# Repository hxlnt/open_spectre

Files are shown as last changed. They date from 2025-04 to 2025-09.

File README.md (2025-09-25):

# OPEN_SPECTRE
## An open-source FPGA-based EMS SPECTRE video synth.
*A project aimed at recreating the EMS SPECTRE VIDEO SYNTHESIZER in HDL*

###  ✨The EMS SPECTRE Colour Video ✨
>Synthesizer is a unique and revolutionary new product: an instrument capable of producing exciting graphic images on an ordinary television screen. The complete SPECTRE package consists of the synthesizer itself, plus a Sony Trinitron colour monitor, and a Sony black-and-white TV camera. The synthesizer is compact (38"x23.5"x7"), portable (about 35 pounds/15.9KG), and unequalled in its simplicity and versatility.

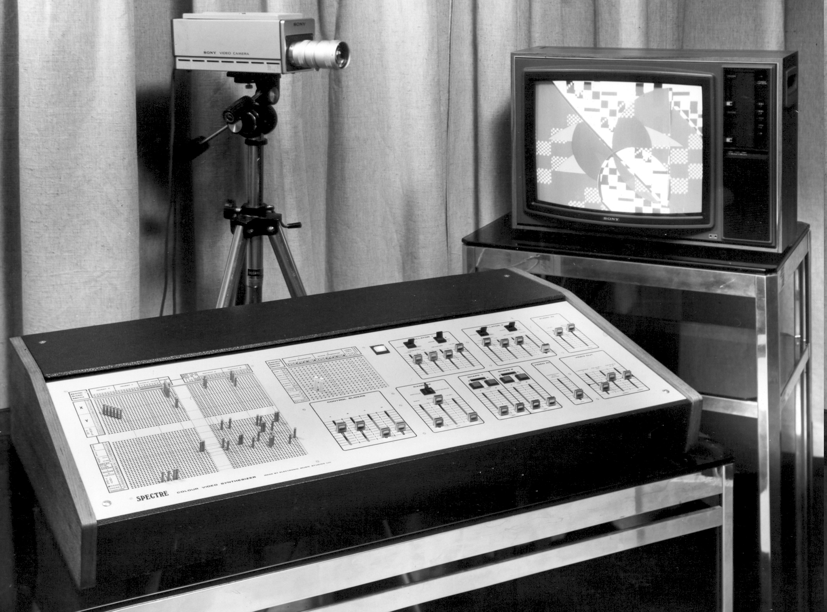
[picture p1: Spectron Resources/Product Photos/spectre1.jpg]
EMS SPECTRE


### Design Info
#### 🎉Aim 🎉
The aim of this project is to preserve this rare and unique video synth by recreating it in an FPGA, but also to use it as a building block to make a Spectre that is both true to the original and also a modern tool for creativity.
For more info in this process take a look at: 
[Cloning Hardware Ethos](documentation/Cloning%20a%20process%20not%20a%20device.md)

### 🍣Want to Contribute?🍣
Amazing! If you have FPGA and or Verilog/VHDL skills we would love to have you involved. But, first, there are a few things you should know. 
#### What to do first
- Look through the resources folder to get an idea of what the EMS SPECTRE is and how it works
- Look at the top-level diagram and the list of modules
#### Project Details For Contributors
- RTL in VHDL or Verilog (VHDL preferred, no system Verilog 😎 sorry) 
- One module per file with a separate testbench (Verilog or VHDL test benches only, *not everything has one yet, but it should)
- Test benches should print out a message at the end confirming if they are successful or not
- No HSL or auto-generated code, no busses or interfaces for now (will be busses later)
- Use any software you like, but a Vivado project will be supplied
- Follow the template for file headers and comments 📑
- Follow the folder structure for the project 📂
- All code must be open source or MIT license 👍

#### If after all that you still want to be involved you can do one of three things:
- Email us at *OPEN.SPECTRE.PROJECT@gmail.com* and see what modules we need to make at the moment
- Branch the repo, make a module, and submit a pull request 
- If you are not any good at git/GitHub, if you write any modules you can email them to us and we will integrate them into the project

### 🐙License🐙
Creative Commons CC BY-NC

### Contributors
-Remi Freer
-Jacob Stoker
-Robert D Jordan

### Donations
We are very thankful to have received donations from the following people:
Chris Korvin,
Jay Hotchin,
Milton Grimshaw, and more amazing anonymous people.

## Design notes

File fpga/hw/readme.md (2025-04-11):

using this dev board:
https://www.aliexpress.com/item/1005005961199362.html?spm=a2g0o.order_list.order_list_main.76.1cc71802oC4QSS
https://github.com/ChinaQMTECH/QMTECH_XC7A15T_35T_CSG325_CORE_BOARD

use these libs
https://github.com/jmwilson/Adafruit-GFX-Library_MicroBlaze
https://github.com/jmwilson/Adafruit_SSD1306_MicroBlaze

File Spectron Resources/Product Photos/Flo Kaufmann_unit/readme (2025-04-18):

Photos of Flo Kaufmann's, generously sent.
Lots of good images of the PCBs

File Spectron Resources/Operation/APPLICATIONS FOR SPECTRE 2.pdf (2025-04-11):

### APPLICATIONS FOR SPECTRE

Spectre is versatile enough to have applications in many diverse fields. Video has already become an aid to education and industry in many ways; Spectre, as a low cost, self-contained video studio is ideal for the school or business wishing to take advantage of video technology. For any educational institution, Spectre will be invaluable as a tool for teaching principles of design, colour, and concepts of digital logic. Students can create works which are easily stored, permanently or temporarily, on videotape, and can be duplicated as easily as with audio recordings. For artists and video production studios, the applications are obvious. As well as being able to perform special effects with less hardware than is usual, Spectre can be used as a live performance instrument, for which there is no comparable system presently available In industry, Spectre will be extremely useful in fields such as fabric and wallpaper design, where a simple photograph of the monitor screen would substitute for painstaking artist's renditions. Black and white images of products or advertisements can be colourised and particular colours or combinations thereof substituted or recalled in an instant. To add to its commercial applications, Spectre is entertaining as well as useful. Its accessibility to even the most inexperienced of users will make it a unique attraction in any situation where entertainment is sought.

OPERATION OF SPECTRE
All patching of functions in Spectre is done by means of pin board matrix connections. Signals coming out of functions appear at horizontal positions (rows) and inputs to functions as well as to the final output, are at vertical positions (columns). Outputs are labelled at the left side of the pin matrix, inputs at the top. In order to produce an image on the monitor screen, signals must eventually reach the input columns of either Output A or Output B, on the Digital Signal Matrix.
Spectre has three types of digital output - luminance, colour 1 and colour 2 - which combine to send particular signal levels to the video output. There are 16 levels of luminance eight levels of each colour, making a total of 64 colour possibilities at any of 16 luminance levels. It is by manipulating the digital signals that produce these levels that we form images on the monitor screen.
In order to operate Spectre effectively, it is helpful to have a basic understanding of digital logic:- Digital signals have only two states: they are either high or low. There are three kinds of operations used to combine digital signals and produce a particular output. These are:
The AND Operation: The output is high only where all inputs are high; where any input is low, the output is low. The OR Operation: The output is high where any input is high; output is low only where all inputs are low. The Exclusive OR Operation: The output is high where only one of two inputs is high; where the two in puts are in the same state the output is low.
With nothing patched on the Digital Signal Matrix, all the digital outputs 'float' high. Signals patched to an output column are combined by the AND operation so that the output will go low wherever the input signal is low. We are, in effect, 'carving' images out of a back screen. With no patching the screen will appear dark. Patching X position 2 (a signal which goes low, high, low, high, low across the screen) to luminance 0 will produce light vertical bands:
The light bands indicate where the luminance signal has been pulled low. Patching X2 also to one of the colour outputs will pull that colour signal low, so that the light bands now have a hue that is the combination of Luminance 0 and one Colour input in the low state, all others in the high state. Input signals patched to the same column also combine by the AND operation.

Beginning as before, with X2 patched to Luminance 0, now patch X4 also to Luminance 0. X4 goes low, high, faster than X2, so producing narrower bands. The bands of X4 will appear only in the positive (high) areas of X2. The dark area on the screen now represents the combined high output of X2 and X4. Output A and Output B are identical, and are combined by the Exclusive OR operation to produce the final digital output of the synthesizer.
To produce a simple checkerboard effect then, we would patch X2 to Luminance 0 at Output A. Now, by patching Y2 to Luminance 0 at Output B, the high level will appear wherever X and Y are in opposite states, the low level wherever they are in the same state. Referring to the graphs at the bottom of page 2, the screen appears like the Exclusive OR graph, repeated several times, dark at the high level, and light at the low level: The effect of any signal may be inverted by grounding the respective input column of the opposite Output That is, if X2 is patched to Luminance 0 at Output A, patching Luminance 0 at Output B to ground will produce this:

SPECTRE FUNCTIONS
Digital Signal Matrix
X and Y positions
Produce horizontal and vertical bands. Each level (0-8) is twice the frequency of the level above it, thus producing bands half the width of the one before.
Overlay Gates (1-4)
Allows superimposition of images. Inputs to SIG appear only where the input to DIS is low.
Inverts (1-4)
Signals sent to Invert inputs appear inverted (high goes low, low goes high) at the Invert out row.
Edge
Creates an image of the border of the signal at the Edge input. If we scan the screen from left to right, we can speak of signals as "rising" where they change from low to high, "falling" where changing from high to low. The + output of the Edge is the border of the rising side of the input signal, - is the border of the falling side.
Delay
Creates "echoes" of signals by reproducing the input signal in the state it was in a microsecond before.
Flip-Flop
Similar to Edge, creating a low signal where the input signal changes state, but extending the edge of the screen. If we send a circle as signal input:
The Flip Flop + output appears:
The Flip-Flop - output appears:
Slow Counter
A signal going high and low at six different frequencies. Can be combined with other functions to produce various timed effects, such as to disenable a signal at an overlay gate
Shape Outputs
There are four separate shape outputs, each of which can produce any of sixteen different signals, as determined by the Shape Select on the right side of the face panel.
Each of these sixteen signals is a basic form which can be modified by a control voltage (such as an Oscillator or Audio signal). Control signal inputs are available on the Analogue Control Matrix (see Shape Select and Shape Generator Control).

Video Input
An input from an external black and white video source (connected via the back panel socket) passes through a comparator in the synthesizer. The comparator divides the grey scale of the video image into seven different levels. These levels appear as digital signal outputs on the Digital Signal Matrix, so that, each of the levels can be individually coloured or patternised. The video output may also be processed through any of the SPECTRE functions, such as Edge or Flip-Flop, for other special effects.
Invert X and Y
Signals at these inputs will cause the corresponding X or Y output to change state wherever the input signal is low. Another way of producing the checkerboard pattern used as an example on page three, is to patch X2 to any level, then patch Y2 to Invert X2.
Colour Swap
Signals patched to any colour are switched to the same level of the opposite colour whenever the input at Colour Swap is low.

Analogue Control Matrix and Sliders
Oscillators 1 and 2
Produce sine and square waves, with slider controls for coarse and fine frequency and amplitude level. Frequency can be switched to one of three ranges. Sync control allows the oscillator to be synched to integer multiples of either the line or frame frequency of the monitor. This allows the effect of the oscillator on an image to remain stable.
Audio Input
Produces an amplitude contour of the treble and bass ranges, or their composite, of any external audio signal. This signal may then be used to alter any voltage controllable parameter of an image.
Control Sliders
Produce voltages which remain constant at the level set on the slider.

From Signal Matrix
Signals directed to the input labelled To Control Matrix (on the Digital Signal Matrix) will appear at this output, with the choice of either the high or low state of the digital signal. Thus, for one instance, the outputs of the Slow counter may be routed to the control matrix to control an analogue function.
Video Out
Signals at these inputs control the level of the final output's luminance, colour 1 and colour 2, as they affect the monitor. Levels for these signals may also be set by face panel sliders. Comparator Level Spacing (Video Input)
This affects the level of the external video input that is directed to the comparator (described on page 5 under Video Input). At maximum, the entire video signal will pass through and be divided into seven levels. At minimum only the darkest areas of the image will pass through and be divided. As the Comparator Level slider or control voltage is changed the colours selected on the Digital Signal Matrix for any level will move from one area of the video image to the next.
Shape Select and Shape Generator Control
The Shape Selects allow the user to choose one of sixteen different signals to appear at one of the four shape outputs on the Digital Signal Matrix. The output chosen is indicated by a combination of four LED's on the Shape Select panel. The Shape Selects and Shape outputs are in pairs: outputs 1a and 1b are controlled by Shape Generator 1, likewise for outputs 2a and 2b controlled by Shape Generator 2.
The sixteen outputs are in turn derived from six basic signals (or forms) produced by the Shape Generators. There are control inputs to each of these six forms, which allow a wide range of modification to any basic form. There are also inputs to control the horizontal and vertical orientation of the forms, making a total of eight control inputs to each Shape Generator. Note that a control signal input to Shape Generator 1 will affect both Shape outputs 1a and 1b, but not 2a or 2b.

SPECTRE SYSTEMS AND ACCESSORIES
SPECTRE may be used with any ordinary television or TV monitor or adapted to the equipment of an existing video set-up. It includes both an encoded video output (either PAL or NTSC format) and a modulated (UHF) output, as well as an un-encoded output for monitors modified to accept its signals directly.
For those who do not already own video equipment, EMS recommends that SPECTRE be purchased as a package with a modified Sony Trinitron colour monitor and Sony black and white TV camera.
The Synthi AKS music synthesizer is recommended as a companion to SPECTRE, allowing a greater range of control signal possibilities, as well as audio-visual interaction.

DESCRIPTION OF COLOUR PLATES
All of the COLOUR plates were taken of images produced by the first prototype of SPECTRE, which is now in operation at the EMS studios in Putney.
Plate 1a: Geometric pattern produced with X-Y generators, with circle overlay. Video feedback is combined to produce colour shifts.
Plate 1b: Simple geometric pattern and 'zoom' shape, with feedback superimposed.
Plate 2a: Electronically-generated image using circle, gear and lantern shapes.
Plate 2b: Also purely electronic - using lantern and 'zoom' shapes, stripes produced by X generators.
Plate 3a: Complex electronically generated pattern, making extensive use of signal inverters.
Plate 3b: Black-and-white camera signal colourized and superimposed over an electronically generated background pattern.
Plate 4a: Geometric pattern with circle and feedback used to invert colours.
Plate 4b: Horizontal 'zoom' shape being modulated by the sine wave output of an oscillator, feedback superimposed.

SPECIFICATIONS
I. CONTROL SYSTEM
A. Digital Signal Matrix (allows combination, structuring and modification of basic signals)
1. Digital Signals:
9 X (Horizontal) Counter Outputs.
strip width: .12us - 30us in binary steps.
9 Y (Vertical) Counter Outputs
Strip Width: 2 lines - 512 lines in binary steps
6 Slow Counter Outputs: 2Hz - 6Hz in binary steps.
4 Shape Outputs (from two independent Shape Generators) each output is panel selectable from 16 possible basic shapes, circle, gear, lantern and triangles being just a few of these. These shapes may be modified by using the Analogue control Matrix.
7 Video Comparator Outputs - each active for a particular grey scale band of the video input. This will perform all the functions of a normal colourizer, and many more as its outputs may be combined and modified with all other matrix functions.
2 External inputs.
2. Digital Signal Modifiers:
9 X Counter Invert inputs
9 Y Counter Invert inputs
2 Flip-Flops (reset with line sync)
4 Overlay Gates (allow build-up of pattern layers) 4 Inverters
1 Edge Generator (with four outputs)
1 Delay (800us, reset with line sync)
3. Digital Matrix Outputs:
The combinations in which a signal is patched to the output columns determines its colour and brightness. There are:
4 bits for brilliance
6 bits for colour
Each bit comes from an "Exclusive OR" gate with both inputs available on the patchboard (named Output A and Output B) This allows the output of each bit to be inverted as required by the user.

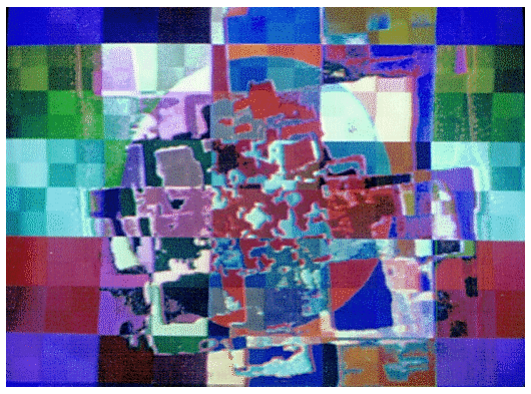
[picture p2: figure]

1 Colour Swap Output (swaps round the two colour parameters)
B. Analogue Control Matrix
(allows voltage control of the two Shape Generators, of the hue and brilliance of the final picture, and of the grey scale spacing of the video comparator.)
Control Sources:
4 Panel Sliders
2 Wide range, High Stability Oscillators 0.1Hz to 50KHz with sine or square outputs, syncable to line or frame sync.
2 Random Voltage outputs, with 'recycle' facility.
2 Envelope Follower outputs - one for bass and one for treble range of any audio input.
1 Buffered audio signal
1 External Input
2 Filtered signals from the Digital Signal Matrix
II. INPUTS
Video Input - 1v p.p. with sync. Other levels may be used if internal presets are altered.
Audio Input - 1v p.p. nominal
External Digital Inputs - normal TTL levels
External Control Inputs +/- 3v maximum
III. SYNC
Internal Sync generator allows full operation without external sync. If external sync is required, all sync inputs are on one

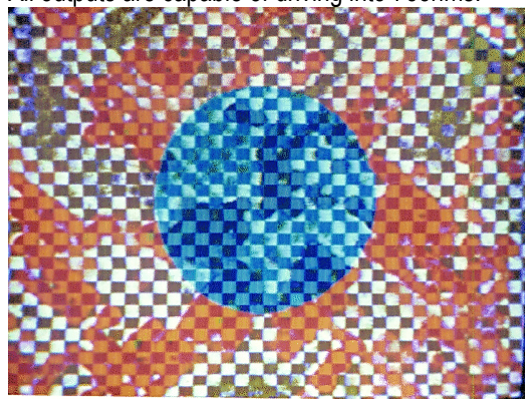
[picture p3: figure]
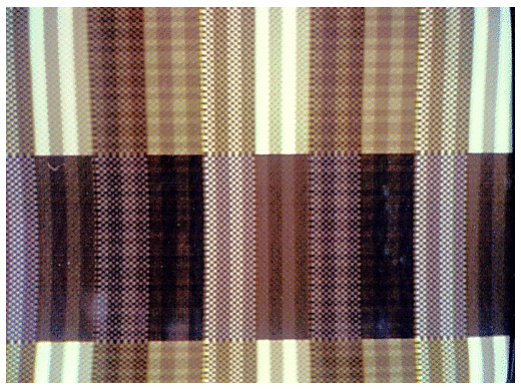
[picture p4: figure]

socket and are 2 - 5 volt -ve going pulses.
Nominal subcarrier input is 2v.
IV. OUTPUTS
Red, Green and Blue Outputs 0.7v with blanking High Resolution output (to modified Sony monitor) Composite PAL (or NTSC by request) output 1v p.p. U.H.F. Output (for direct connection to any colour TV) All outputs are capable of driving into 75ohms.

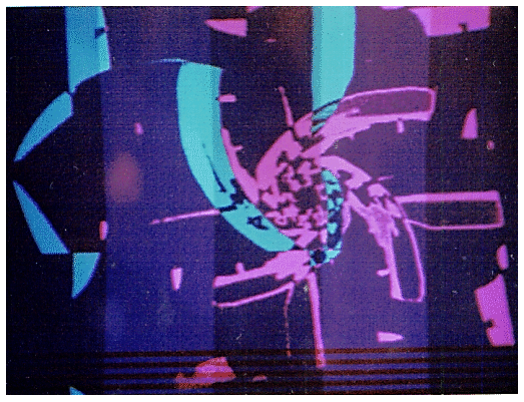
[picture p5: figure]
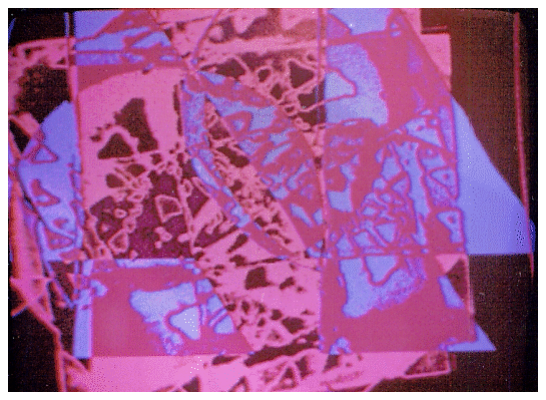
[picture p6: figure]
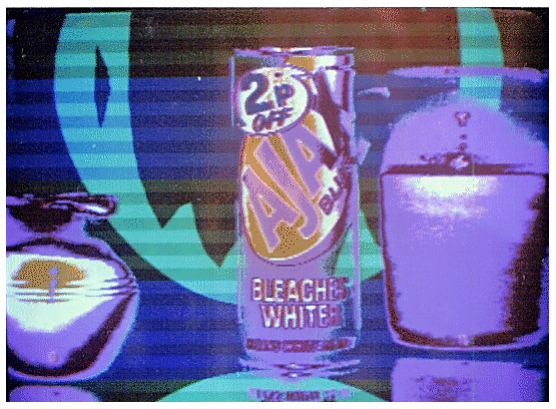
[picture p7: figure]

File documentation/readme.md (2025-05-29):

Design Hierarchy
* = tested and passed
<pre>
-------------------------------------------------------------
Hierarchy of tb_test_digital_side is:
    
**** INDIVIDUAL MODULES PASSED 100% ****
tb_test_digital_side (tested and appears fully working)
    ├─ test_digital_side : test_digital_side (*)
        │   ├─ counter : counter_re (*)
        │   ├─ counter : counter_re (*)
        │   ├─ xor18 : xy_invert_logic (*)
        │   ├─ slow_counter : slow_counter (*)
                │   ├─ pulse_generator : hz6_counter 
                │   ├─ pulse_generator : hz3_counter
                │   ├─ pulse_generator : hz1_5_counter
                │   ├─ pulse_generator : hz_6_counter
                │   ├─ pulse_generator : hz_4_counter
                │   ├─ pulse_generator : hz_2_counter
        │   ├─ nand4 : overlay_gates (*)
        │   ├─ invert_4 : inverters (*)
        │   ├─ monstable_4 : edge (*)
                │   ├─ edge_detector : ed_1 
                │   ├─ edge_detector : ed_2
                │   ├─ edge_detector : ed_3
                │   ├─ edge_detector : ed_4
        │   ├─ delay_800us : delay_800 (*)
        │   ├─ d_flipflop_ext : flip_flop1 (*)
        │   ├─ d_flipflop_ext : flip_flop2 (*)
        │   ├─ compare_7 : comparator (*)
                │   ├─ window_comparator : wc_5 (*)
                │   ├─ window_comparator : wc_4 (*)
                │   ├─ window_comparator : wc_3 (*)
                │   ├─ window_comparator : wc_2 (*)
                │   ├─ window_comparator : wc_1 (*)
                │   ├─ window_comparator : wc_0 (*)
                │   ├─ xor_n : xor_n (*)
        │   ├─ xor_n : matrix_input_inverters (*)
        │   ├─ or_matrix_full : pin_matrix (*)
                │   ├─ xpoint_or : or_mattrix 
        │   ├─ xor_n : luma_output (*)
        │   ├─ mux_5 : chroma_output (*)
                │   ├─ mux2_1 : mux1 
                │   ├─ mux2_1 : mux2
                │   ├─ mux2_1 : mux3
                │   ├─ mux2_1 : mux4
                │   ├─ mux2_1 : mux5
                │   ├─ mux2_1 : mux6
    ├─ write_file_ex : write_file_ex (* simulation only)
-------------------------------------------------------------    
</pre>
<pre>
-------------------------------------------------------------
Hierarchy of tb_analog_side is: !!NEED TO REGENERATE IS MISSING ATTENUATORS AND SLEW MODULES!!

tb_analog_side
    ├─ analog_side : analog_side 
        │   ├─ adder_12bit_nooverflow : pos_h_1_mix (*) -- these should be adder subtractors, acting more like an offset to the values from the analog matrix 
        │   ├─ adder_12bit_nooverflow : pos_v_1_mix (*)
        │   ├─ adder_12bit_nooverflow : zoom_h_1_mix (*)
        │   ├─ adder_12bit_nooverflow : zoom_v_1_mix (*)
        │   ├─ adder_12bit_nooverflow : circle_1_mix (*)
        │   ├─ adder_12bit_nooverflow : gear_1_mix (*)
        │   ├─ adder_12bit_nooverflow : lantern_1_mix (*)
        │   ├─ adder_12bit_nooverflow : fizz_1_mix (*)
        │   ├─ mixer_interface : analox_matrix (*)
                │   ├─ analog_matrix : analog_matrix (*)
                        │   ├─ audiomixer : audiomixer (*)
                        │   ├─ audiomixer : audiomixer
                        │   ├─ audiomixer : audiomixer
                        │   ├─ audiomixer : audiomixer
                        │   ├─ audiomixer : audiomixer
                        │   ├─ audiomixer : audiomixer
                        │   ├─ audiomixer : audiomixer
                        │   ├─ audiomixer : audiomixer
                        │   ├─ audiomixer : audiomixer
                        │   ├─ audiomixer : audiomixer
                        │   ├─ audiomixer : audiomixer
                        │   ├─ audiomixer : audiomixer
                        │   ├─ audiomixer : audiomixer
                        │   ├─ audiomixer : audiomixer
                        │   ├─ audiomixer : audiomixer
                        │   ├─ audiomixer : audiomixer
                        │   ├─ audiomixer : audiomixer
                        │   ├─ audiomixer : audiomixer
                        │   ├─ audiomixer : audiomixer
                        │   ├─ audiomixer : audiomixer
        │   ├─ sinwavegenerator : osc1 (*)
        │   ├─ sinwavegenerator : osc2 (*)
        │   ├─ random_voltage: random_1 (*)
                │   ├─ shift_sipo : sipo_1 (*)
                │   ├─ shift_sipo : sipo_2 (*)
                │   ├─ mux_8_to_1 : mux_random (*)
                │   ├─ counter : random_freq (*)
                │   ├─ slew_wraper : slew_output_1 (*)
                        │   ├─ moving_average : slew_fast  (*)
                        │   ├─ moving_average : slew_med (*)
                        │   ├─ moving_average : slew_slow (*)
                        │   ├─ moving_average : slew_snail (*)
                │   ├─ slew_wraper : slew_output_2 (*)
                        │   ├─ moving_average : slew_fast (*)
                        │   ├─ moving_average : slew_med (*)
                        │   ├─ moving_average : slew_slow (*)
                        │   ├─ moving_average : slew_snail (*)
        │   ├─ adder_12bit_nooverflow : y_dig_ann_mix (*)
        │   ├─ adder_12bit_nooverflow : u_dig_ann_mix (*)
        │   ├─ adder_12bit_nooverflow : v_dig_ann_mix (*)
        │   ├─ yuv_levels : yuv_out_levels (*)
                │   ├─ alphablend : alphablend (*)
                │   ├─ alphablend : alphablend (*)
                │   ├─ alphablend : alphablend (*)
-------------------------------------------------------------
</pre>

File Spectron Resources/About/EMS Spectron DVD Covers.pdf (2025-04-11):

# EMS Spectron Video Synthesizer

The EMS Colour Video Synthesizer is a completely unique and revolutionary development in video hardware. The Spectron is an instrument capable of creating exciting graphic image on an ordinary television screen. It can be used to process and manipulate images fed to it from a TV camera or VTR, or to create dramatic and evocative abstract images without the need for an external signal source.

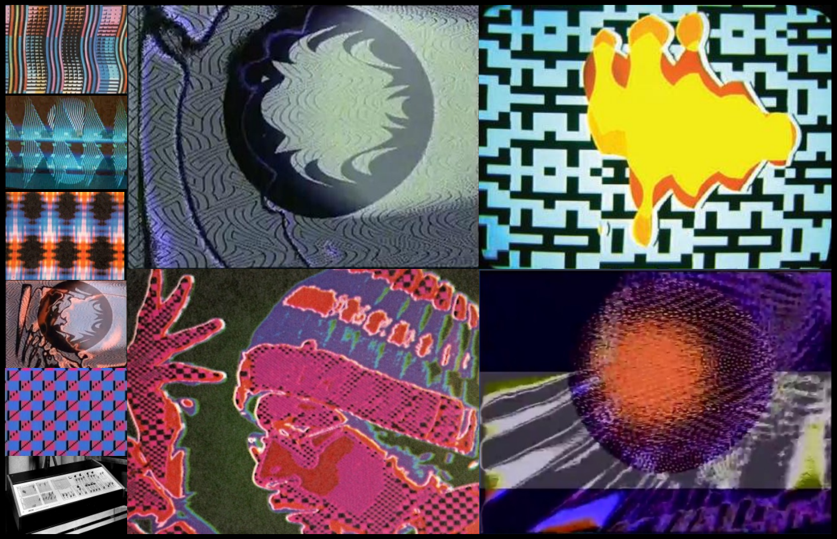
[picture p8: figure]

The Spectron Video Synthesizer is similar to the now familiar audio synthesizer. It incorporates a number of separate functions which can be selected and combined by the user by means of patch boards on the front face panel. The number of possible combinations is virtually infinite, allowing an unlimited variety of images, colours and patterns to be produced. Two specially-prepared DVDs are presented showcasing the capabilities and functions of the Spectron along with technical information and a rich source of visual references. Along with the many examples of Spectron-generated video graphics are picture galleries, information on Richard Monkhouse (the Spectron’s electronics designer and engineer), the article the Moving Art of Video Graphics, and information on video synthesis as an evolutionary phenomenon.

# EMS Spectron Video Synthesizer

A selected variety of examples has been chosen to portray the unique capabilities of the Spectron video synthesizer. All examples have been re-mastered and prepared in wide-screen format with additional sound as required.

DISC 1 | RM Spectron Demonstrations Mother Earth by Zorch Le Entrapercu by Robert Cahen Lucifer Photophore Quad Display Labyrinthe Fluides with Information Text Variations Video I – Jacques Guyonnet Horizontales Couleurs – Robert Cahen Artmatique – Robert Cahen Art Electronique
DISC 2 | Telex – Twist a St. Tropez Tangerine Dream Richocet Excerpt Todd Rundgren – All The Children Sing Plastic Bertrand – Ca Plane Pour Moi Indefinite Objects Quad Display Sans Soleil Film Spectron Excerpts EMS Spectron Logic Demonstrations Indefinite Objects NVC

SPECIAL FEATURES
| Technical Information Picture Gallery Richard Monkhouse & the EMS Spectron The Moving Art of Video Graphics Spectron Grammar Video Synthesis Directions

DVD videos for personal reference material only.

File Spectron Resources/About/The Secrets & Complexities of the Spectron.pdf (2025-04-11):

# THE SECRETS & COMPLEXITIES OF THE SPECTRON

FEEDBACK EFFECTS
Surreal effects can be produced by incorporating optical video feedback into the signal chain, and using the extensive image processing capability of the Spectron to produce all kinds of inverted colourisation effects, negative imagery, and effects that can “shimmer” or “vibrate” on the screen. Here, the Spectron is used as a kind of colourisation vision mixer.

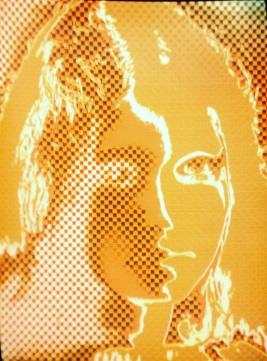
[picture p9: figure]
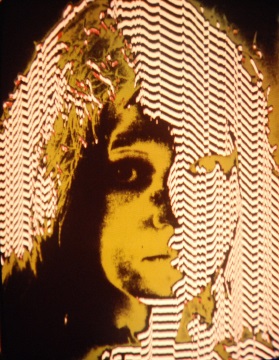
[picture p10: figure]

COUNTER ADDITION EFFECTS

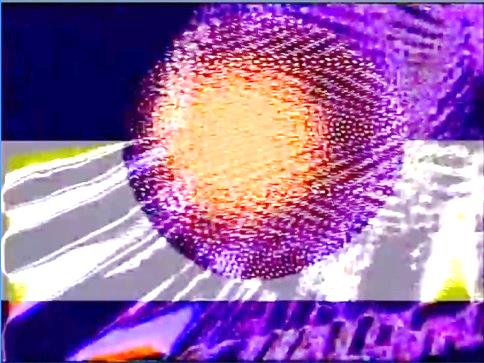
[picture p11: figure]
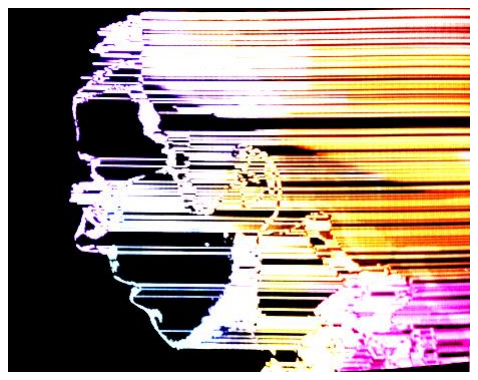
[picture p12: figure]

Sets of pins in the same “column” on the patch board do a wired OR function. If you OR a series of X counter outputs one obtains thin vertical lines. If one then performs an XOR to the INVERT input of each X counter bit with the appropriate Y counter, one effectively makes a kind of digital adder, and the vertical lines can be turned into diagonal lines. Experimentation can yield diamond patterns and other variations of diagonally-formed combinations.

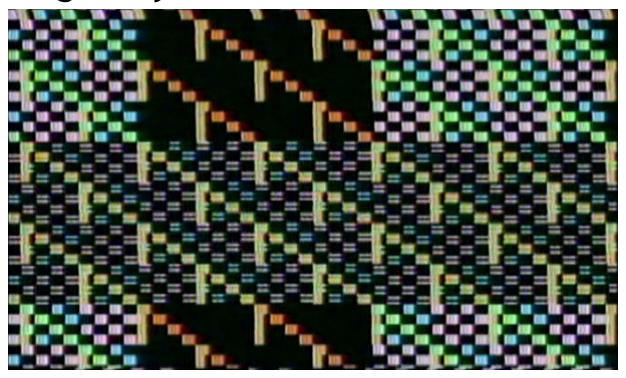
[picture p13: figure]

FRACTALS

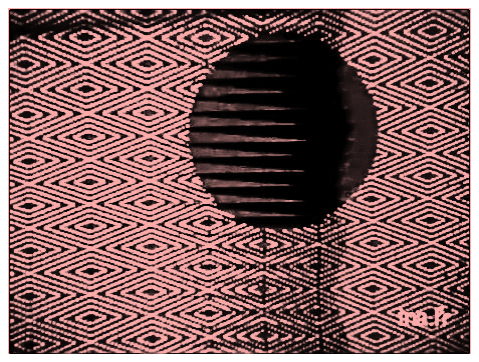
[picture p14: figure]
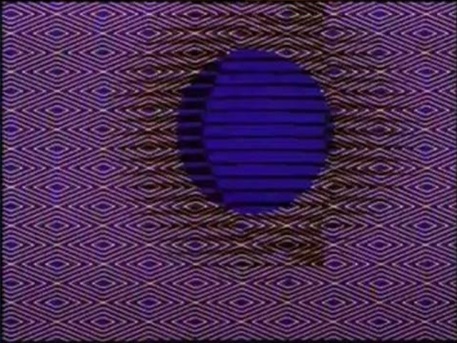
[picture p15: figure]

Quite complex “fractal-like” patterns can be produced by integrating generators and processors with an internal feedback loop. Feedback can be created by the ACM controlling a shape generated and fed into the DSM, which in turn cycles back to the analogue domain.

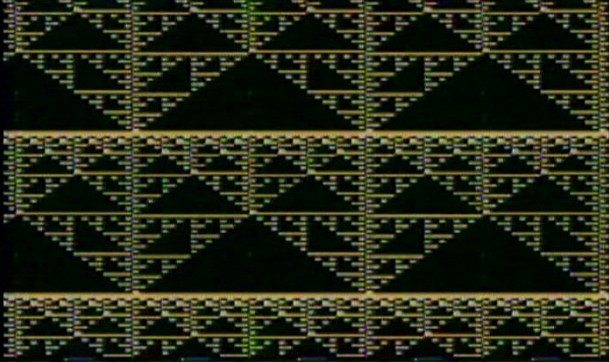
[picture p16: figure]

THE UNEXPLAINED

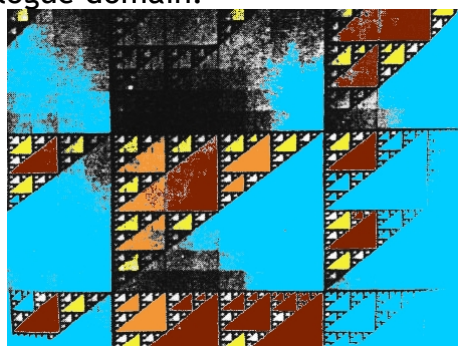
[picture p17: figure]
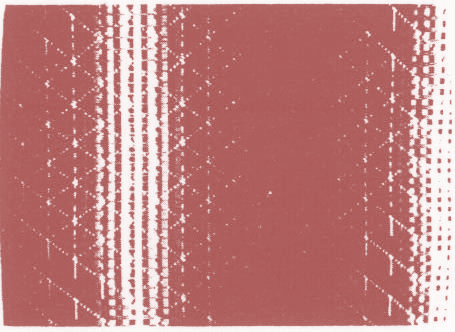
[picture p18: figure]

One of the mysteries of the counter logic combinations is the “maze patch” from the Labyrinthe Fluides video by Genevieve Calame & Jacques Guyonnet. The “digital adder” technique is used here with the X and Y counters in a particular combination that has not been explained. All that is known is that many, if not all, logic combinations of a set of binary bits can be made by asymmetric functions such as AND and OR, and inversion symmetrical controlled inversion , ie. XOR.

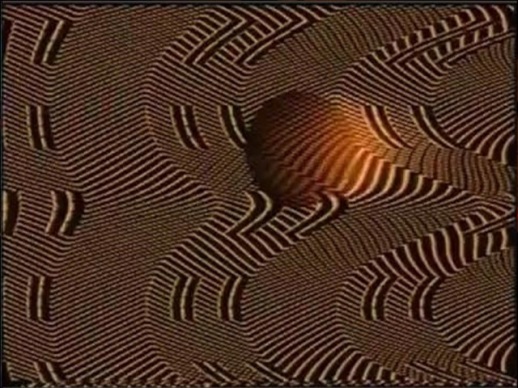
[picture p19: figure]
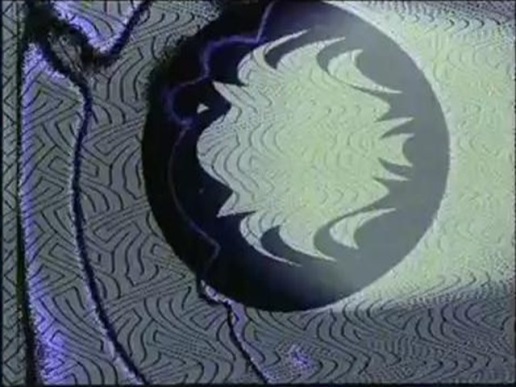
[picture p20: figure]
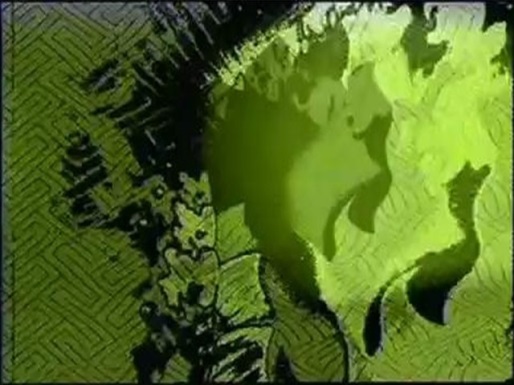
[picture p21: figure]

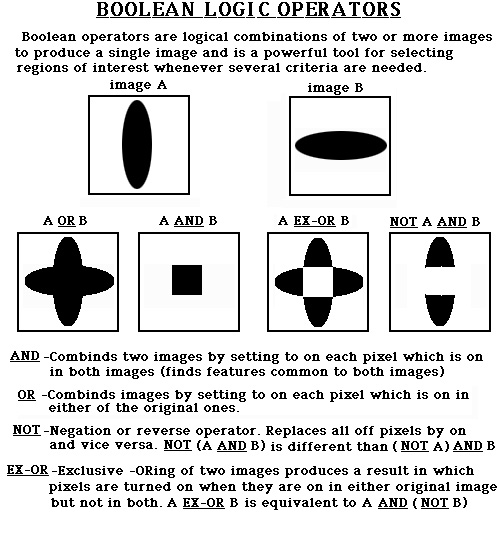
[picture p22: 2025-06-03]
Spectron Resources/Product Photos/Boolean Logic.jpg

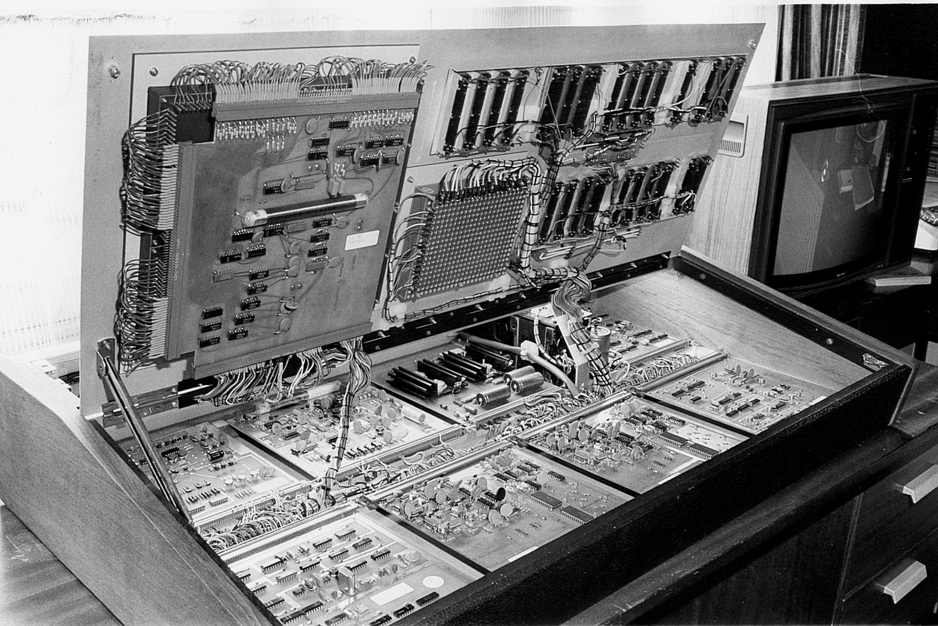
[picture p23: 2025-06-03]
Spectron Resources/Product Photos/spectre2x.jpg

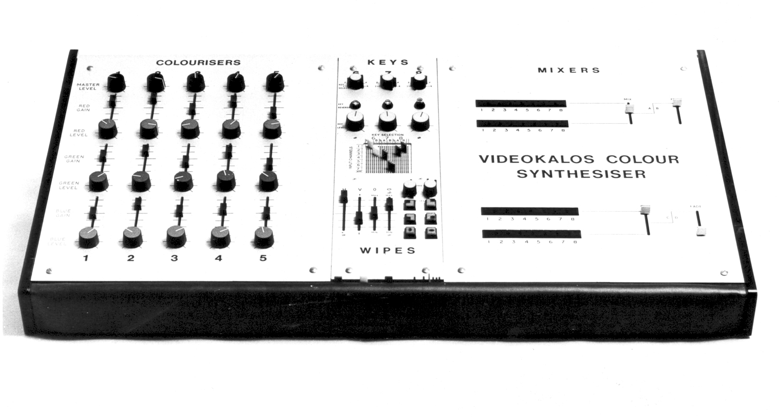
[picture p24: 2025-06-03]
Spectron Resources/Product Photos/Other machines/videok.jpg

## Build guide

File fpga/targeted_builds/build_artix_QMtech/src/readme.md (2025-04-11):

Files used in the hardware proto build On QMtech artix dev board

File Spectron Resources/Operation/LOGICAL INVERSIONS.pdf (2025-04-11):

## LOGICAL INVERSIONS & EXCLUSIVE OR (XOR) TRANSFORMATIONS

Linear counters (horizontal & vertical) and checkerboard patterns are transformed by the XOR logical transformation and linear movements that are imparted. Several orders of XOR logic and track-matte functions create complex combinations from simple patterned effects.

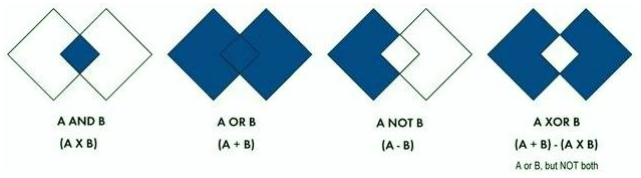
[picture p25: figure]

Logical AND, OR and XOR combinations produce many complex visualisations that can create startling optical animations. The full visual potential of the exclusive OR (XOR) function on linear and checkerboard patterns has yet to be realised. Because of the availability of the XOR effect on any image within the video layers, the power of XOR goes well beyond simple inversion. This is the appeal of the XOR - pure logic functioning that transcends the concept of the image.

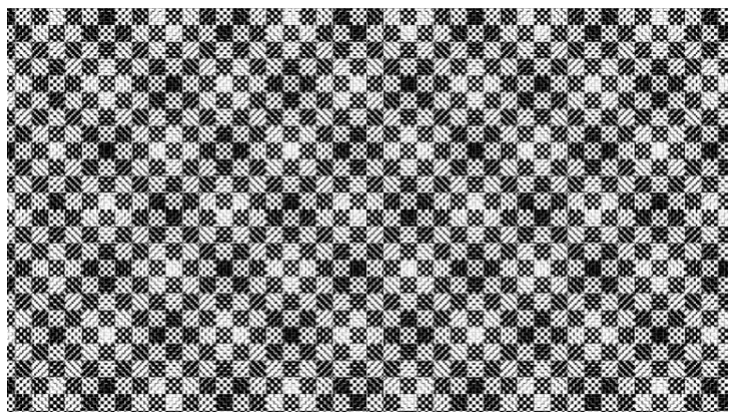
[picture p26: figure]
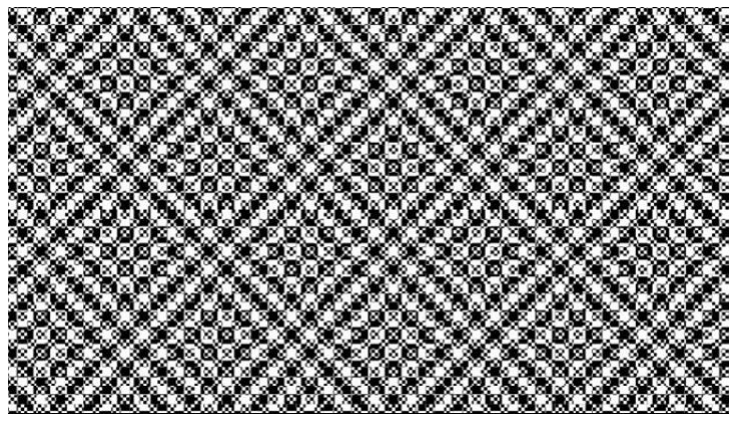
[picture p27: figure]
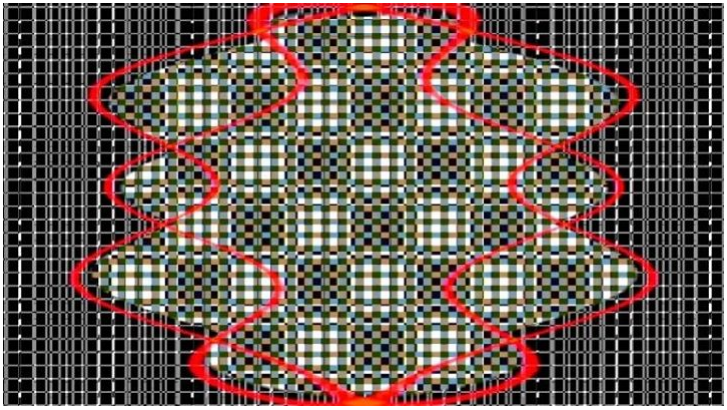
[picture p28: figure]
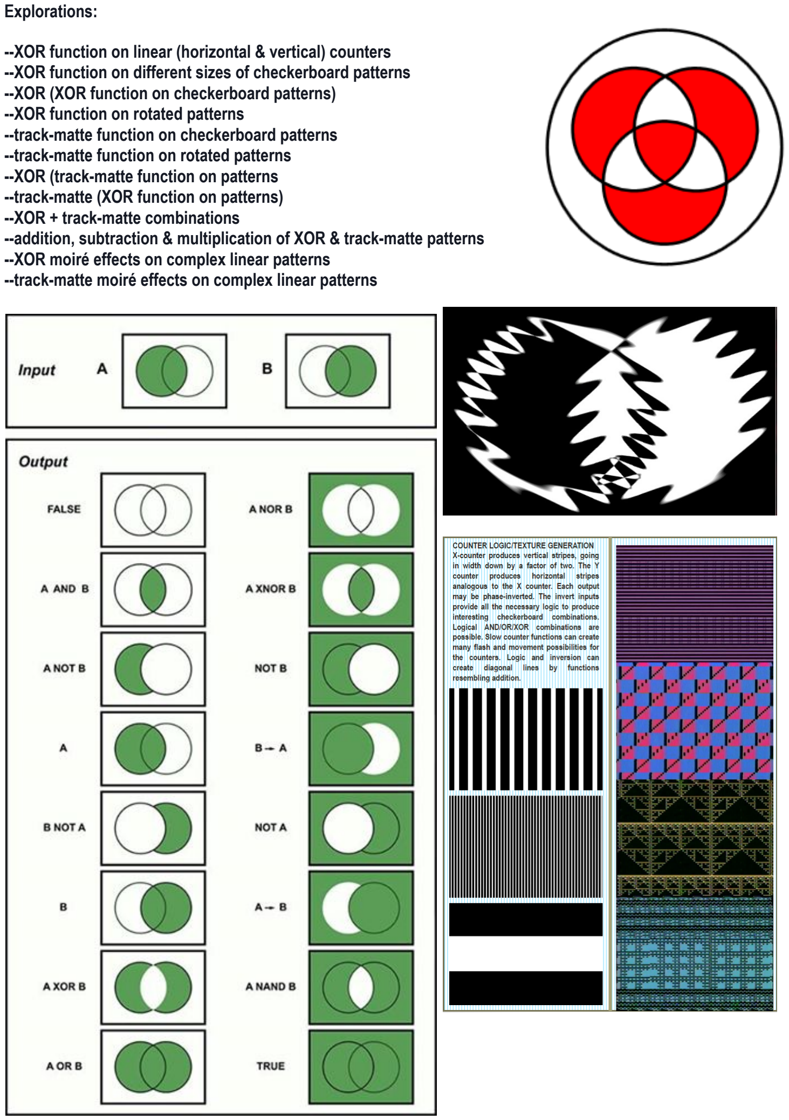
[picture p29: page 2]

Explorations:

--XOR function on linear (horizontal & vertical) counters --XOR function on different sizes of checkerboard patterns --XOR (XOR function on checkerboard patterns)
--XOR function on rotated patterns
--track-matte function on checkerboard patterns --track-matte function on rotated patterns --XOR (track-matte function on patterns
--track-matte (XOR function on patterns)
--XOR + track-matte combinations
--addition, subtraction & multiplication of XOR & track-matte patterns --XOR moiré effects on complex linear patterns
--track-matte moiré effects on complex linear patterns

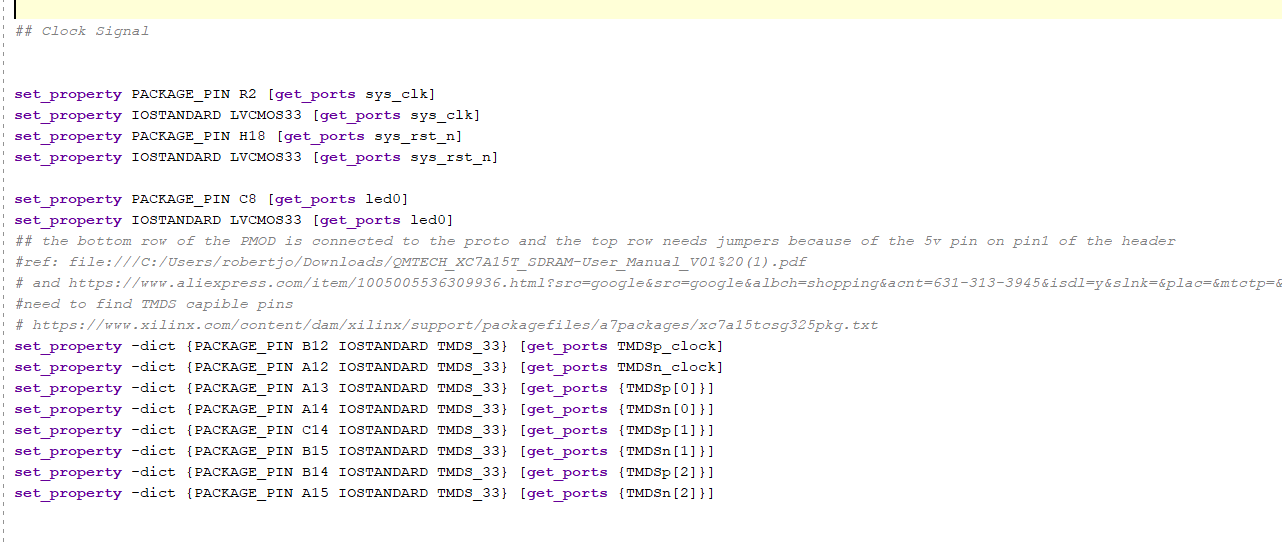
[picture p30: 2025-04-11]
fpga/targeted_builds/build_artix_QMtech_hdmi_out_test/pins.PNG

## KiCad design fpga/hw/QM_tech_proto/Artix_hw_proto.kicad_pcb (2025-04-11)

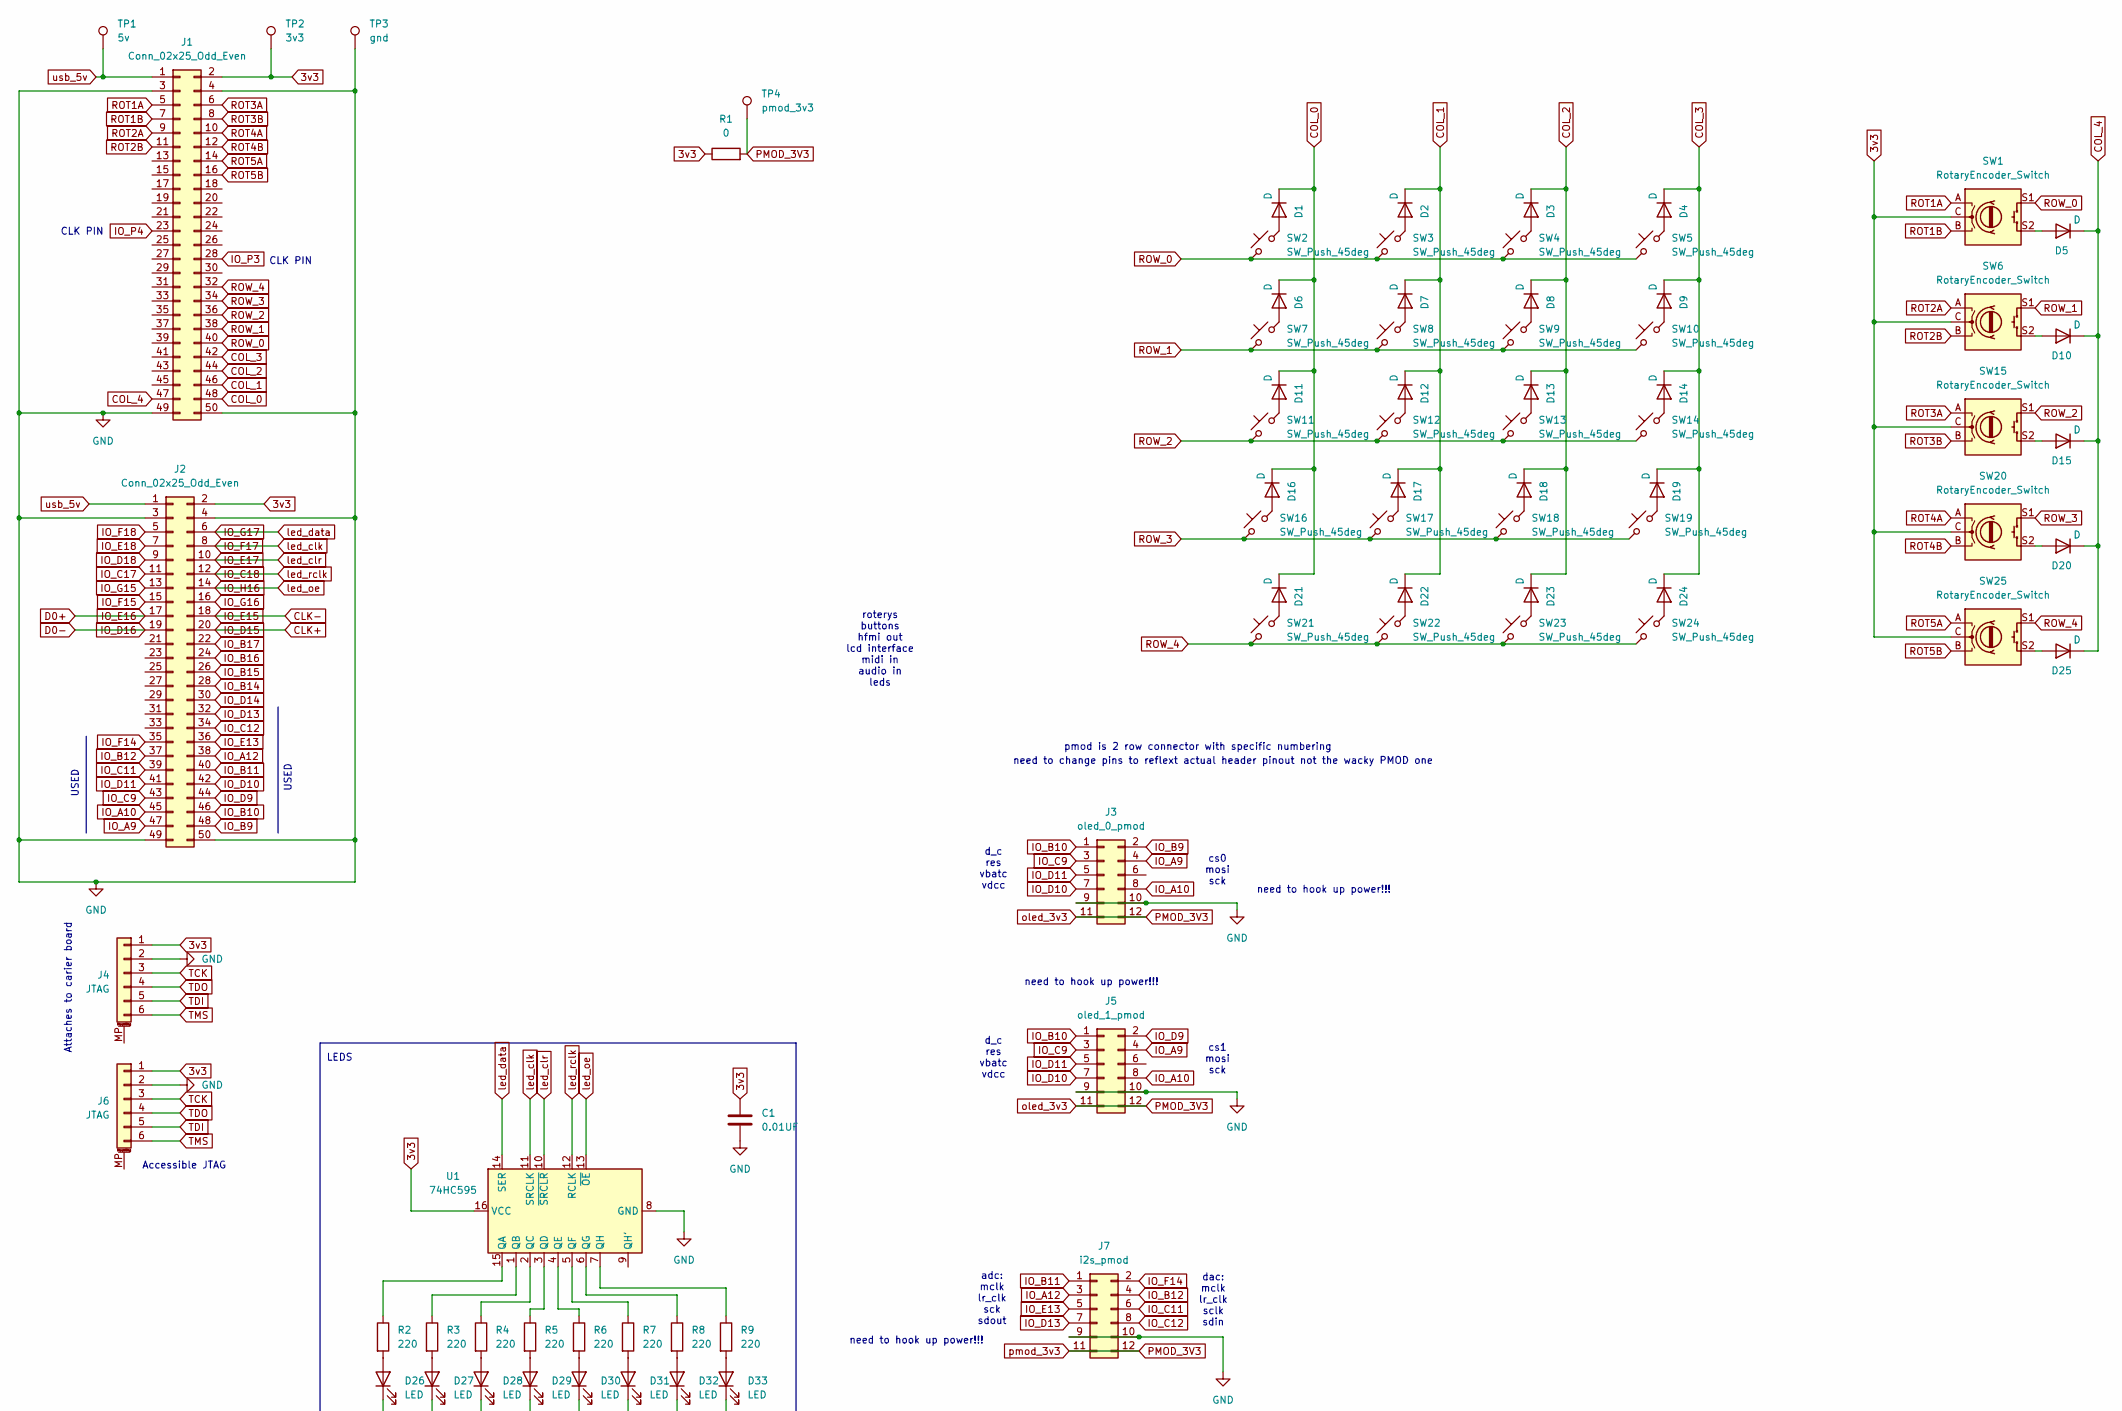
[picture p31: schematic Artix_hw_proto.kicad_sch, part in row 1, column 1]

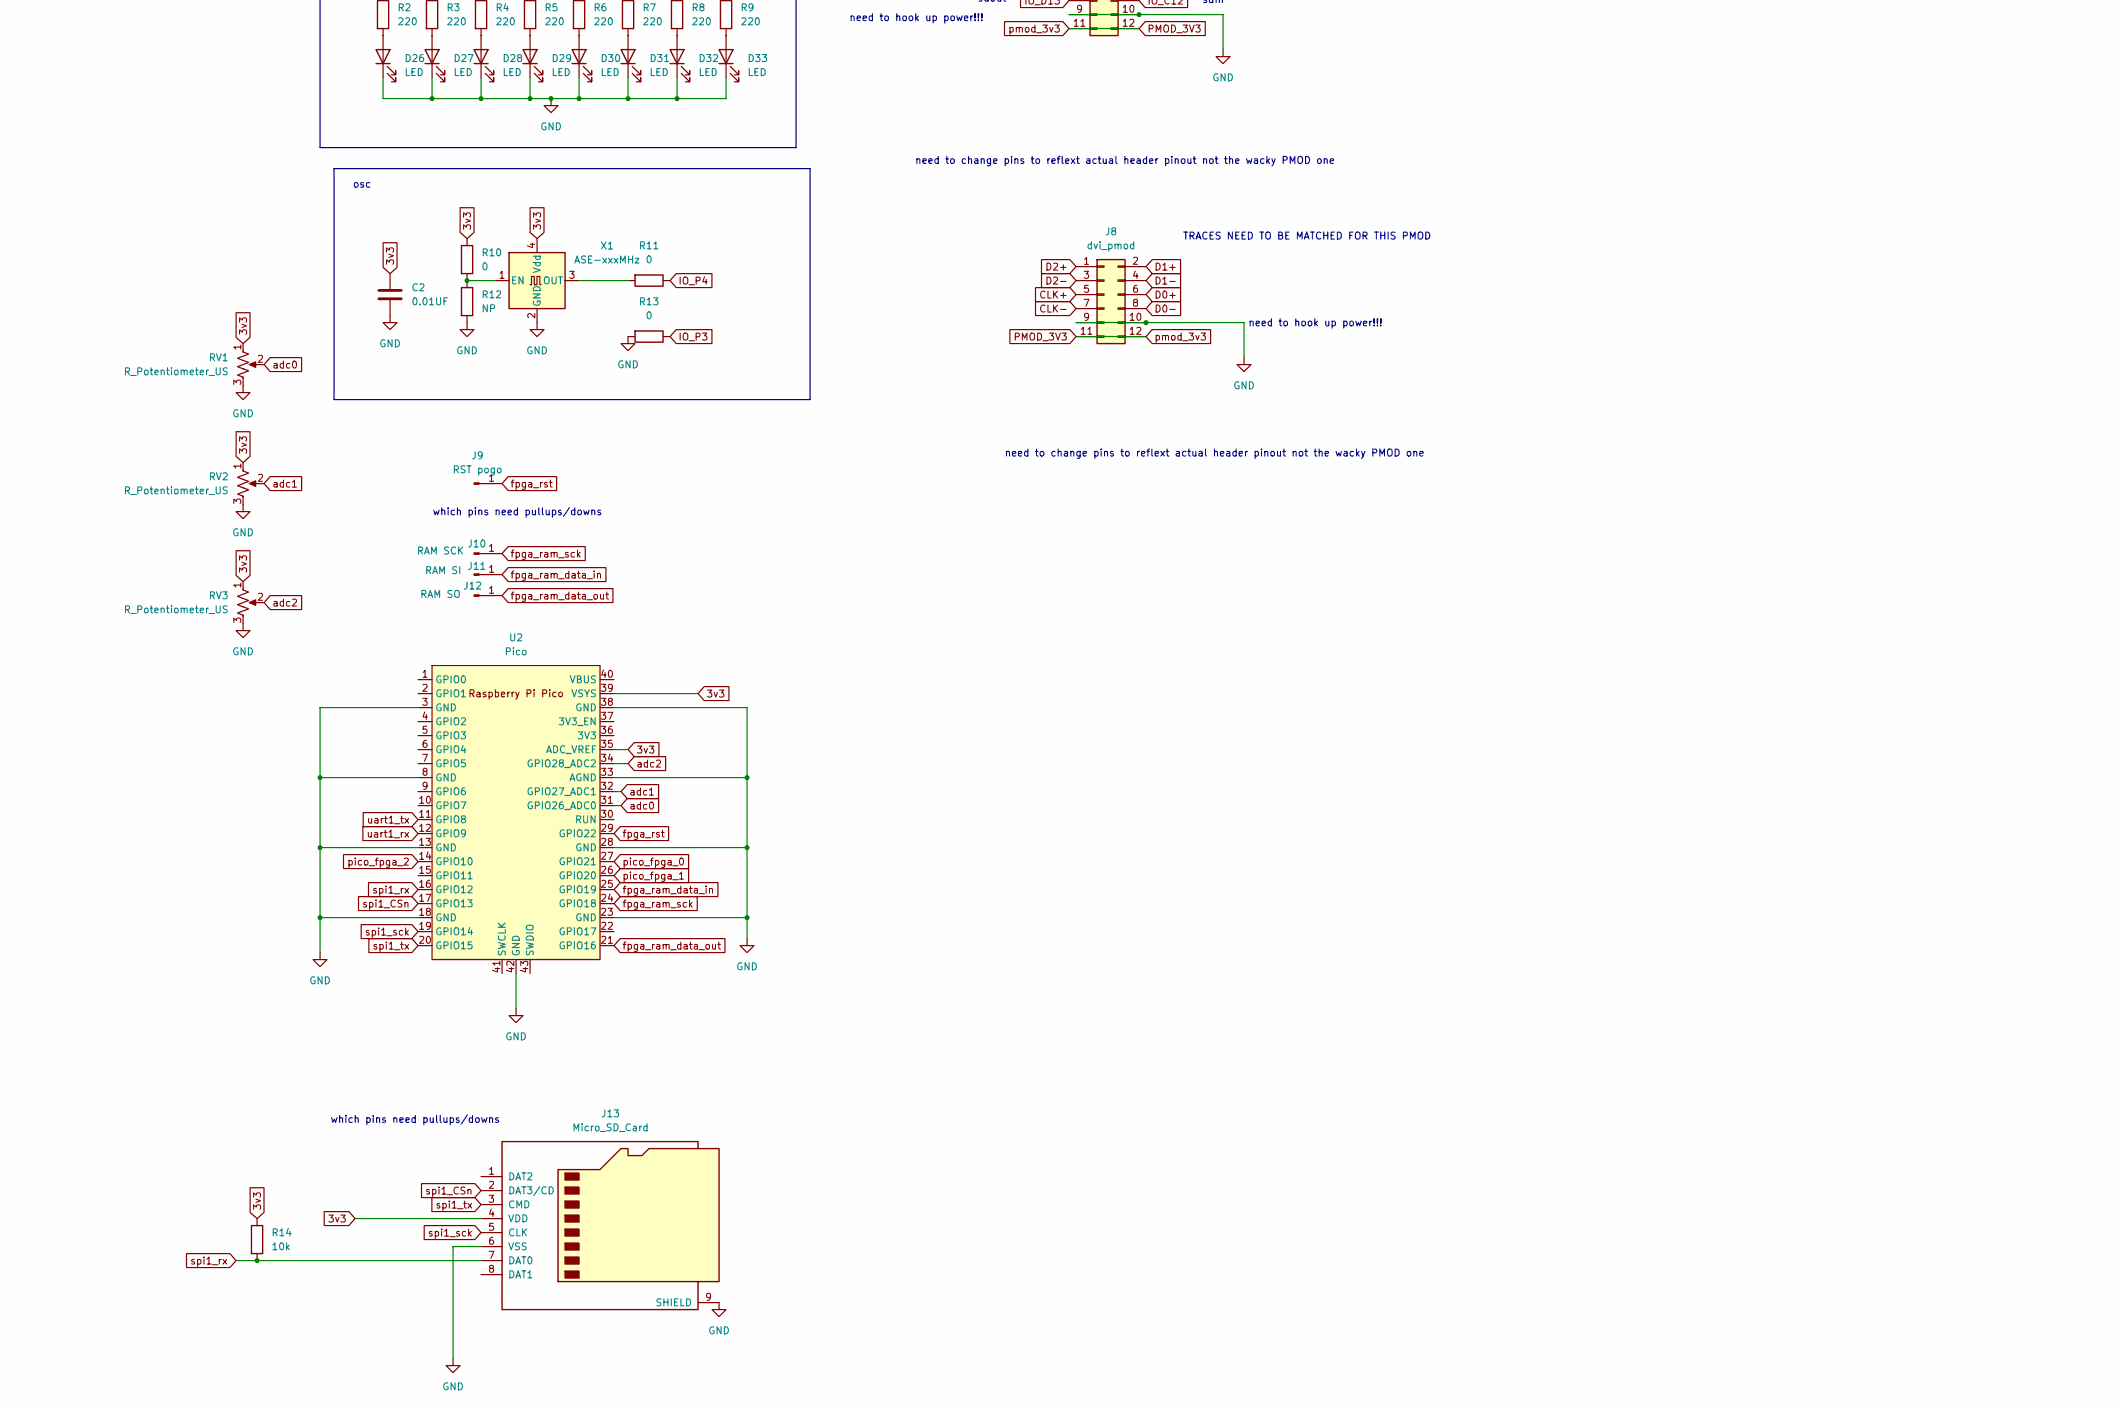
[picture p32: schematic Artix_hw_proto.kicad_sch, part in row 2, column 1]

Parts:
C1, C2: 0.01UF; C_Axial_L3.8mm_D2.6mm_P7.50mm_Horizontal
D1, D2, D3, D4, D5, D6, D7, D8, D9, D10, D11, D12, D13, D14, D15, D16, D17, D18, D19, D20, D21, D22, D23, D24, D25: D; D_MELF-RM10_Universal_Handsoldering
D26, D27, D28, D29, D30, D31, D32, D33: LED; LED_D3.0mm_FlatTop
J1, J2: Conn_02x25_Odd_Even; PinSocket_2x25_P2.54mm_Vertical
J3: oled_0_pmod; PinSocket_2x06_P2.54mm_Horizontal
J4, J6: JTAG; PinHeader_1x06_P2.54mm_Vertical
J5: oled_1_pmod; PinSocket_2x06_P2.54mm_Horizontal
J7: i2s_pmod; PinSocket_2x06_P2.54mm_Horizontal
J8: dvi_pmod; PinSocket_2x06_P2.54mm_Horizontal
J9: RST pogo; PinHeader_1x01_P2.54mm_Vertical
J10: RAM SCK; PinHeader_1x01_P2.54mm_Vertical
J11: RAM SI; PinHeader_1x01_P2.54mm_Vertical
J12: RAM SO; PinHeader_1x01_P2.54mm_Vertical
J13: Micro_SD_Card; microSD_HC_Wuerth_693072010801
R1, R10, R11, R13: 0; R_0805_2012Metric_Pad1.20x1.40mm_HandSolder
R2, R3, R4, R5, R6, R7, R8, R9: 220; R_0805_2012Metric_Pad1.20x1.40mm_HandSolder
R12: NP; R_0805_2012Metric_Pad1.20x1.40mm_HandSolder
R14: 10k; R_0805_2012Metric_Pad1.20x1.40mm_HandSolder
RV1, RV2, RV3: R_Potentiometer_US; Potentiometer_Alpha_RD901F-40-00D_Single_Vertical_CircularH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
SW1, SW6, SW15, SW20, SW25: RotaryEncoder_Switch; RotaryEncoder_Alps_EC11E-Switch_Vertical_H20mm
SW2, SW3, SW4, SW5, SW7, SW8, SW9, SW10, SW11, SW12, SW13, SW14, SW16, SW17, SW18, SW19, SW21, SW22, SW23, SW24: SW_Push_45deg; SW_PUSH_6mm
TP1: 5v; TestPoint_Loop_D1.80mm_Drill1.0mm_Beaded
TP2: 3v3; TestPoint_Loop_D1.80mm_Drill1.0mm_Beaded
TP3: gnd; TestPoint_Loop_D1.80mm_Drill1.0mm_Beaded
TP4: pmod_3v3; TestPoint_Loop_D1.80mm_Drill1.0mm_Beaded
U1: 74HC595; DIP-16_W7.62mm_SMDSocket_SmallPads
U2: Pico; RPi_Pico_SMD_TH
X1: ASE-xxxMHz; Oscillator_SMD_Abracon_ASE-4Pin_3.2x2.5mm

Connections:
3v3: C1.1, C2.1, J1.2, J2.2, J4.1, J6.1, J13.4 (VDD), R1.1, R10.1, R14.1, RV1.1, RV2.1, RV3.1, SW1.C, SW6.C, SW15.C, SW20.C, SW25.C, TP2.1, U1.16 (VCC), U2.35 (ADC_VREF), U2.39 (VSYS), X1.4 (Vdd)
CLK+: J2.20, J8.5
CLK-: J2.18, J8.7
COL_0: D1.1 (K), D6.1 (K), D11.1 (K), D16.1 (K), D21.1 (K), J1.48
COL_1: D2.1 (K), D7.1 (K), D12.1 (K), D17.1 (K), D22.1 (K), J1.46
COL_2: D3.1 (K), D8.1 (K), D13.1 (K), D18.1 (K), D23.1 (K), J1.44
COL_3: D4.1 (K), D9.1 (K), D14.1 (K), D19.1 (K), D24.1 (K), J1.42
COL_4: D5.1 (K), D10.1 (K), D15.1 (K), D20.1 (K), D25.1 (K), J1.47
D0+: J2.17, J8.6
D0-: J2.19, J8.8
D1+: J8.2
D1-: J8.4
D2+: J8.1
D2-: J8.3
GND: C1.2, C2.2, D26.1 (K), D27.1 (K), D28.1 (K), D29.1 (K), D30.1 (K), D31.1 (K), D32.1 (K), D33.1 (K), J1.3, J1.4, J1.49, J1.50, J2.3, J2.4, J2.49, J2.50, J3.9, J3.10, J4.2, J5.9, J5.10, J6.2, J7.9, J7.10, J8.9, J8.10, J13.6 (VSS), J13.9 (SHIELD), R12.2, R13.2, RV1.3, RV2.3, RV3.3, TP3.1, U1.8 (GND), U2.3 (GND), U2.8 (GND), U2.13 (GND), U2.18 (GND), U2.23 (GND), U2.28 (GND), U2.33 (AGND), U2.38 (GND), U2.42 (GND), X1.2 (GND)
IO_A9: J2.47, J3.4, J5.4
IO_A10: J2.45, J3.8, J5.8
IO_A12: J2.38, J7.3
IO_B9: J2.48, J3.2
IO_B10: J2.46, J3.1, J5.1
IO_B11: J2.40, J7.1
IO_B12: J2.37, J7.4
IO_B14: J2.28
IO_B15: J2.26
IO_B16: J2.24
IO_B17: J2.22
IO_C9: J2.43, J3.3, J5.3
IO_C11: J2.39, J7.6
IO_C12: J2.34, J7.8
IO_C17: J2.11
IO_C18: J2.12, U1.12 (RCLK)
IO_D9: J2.44, J5.2
IO_D10: J2.42, J3.7, J5.7
IO_D11: J2.41, J3.5, J5.5
IO_D13: J2.32, J7.7
IO_D14: J2.30
IO_D18: J2.9
IO_E13: J2.36, J7.5
IO_E17: J2.10, U1.10 (~SRCLR)
IO_E18: J2.7
IO_F14: J2.35, J7.2
IO_F15: J2.15
IO_F17: J2.8, U1.11 (SRCLK)
IO_F18: J2.5
IO_G15: J2.13
IO_G16: J2.16
IO_G17: J2.6, U1.14 (SER)
IO_H16: J2.14, U1.13 (~OE)
IO_P3: J1.28, R13.1
IO_P4: J1.23, R11.1
unnamed: D1.2 (A), SW2.2
unnamed: D2.2 (A), SW3.2
unnamed: D3.2 (A), SW4.2
unnamed: D4.2 (A), SW5.2
unnamed: D5.2 (A), SW1.S2
unnamed: D6.2 (A), SW7.2
unnamed: D7.2 (A), SW8.2
unnamed: D8.2 (A), SW9.2
unnamed: D9.2 (A), SW10.2
unnamed: D10.2 (A), SW6.S2
unnamed: D11.2 (A), SW11.2
unnamed: D12.2 (A), SW12.2
unnamed: D13.2 (A), SW13.2
unnamed: D14.2 (A), SW14.2
unnamed: D15.2 (A), SW15.S2
unnamed: D16.2 (A), SW16.2
unnamed: D17.2 (A), SW17.2
unnamed: D18.2 (A), SW18.2
unnamed: D19.2 (A), SW19.2
unnamed: D20.2 (A), SW20.S2
unnamed: D21.2 (A), SW21.2
unnamed: D22.2 (A), SW22.2
unnamed: D23.2 (A), SW23.2
unnamed: D24.2 (A), SW24.2
unnamed: D25.2 (A), SW25.S2
unnamed: D26.2 (A), R2.2
unnamed: D27.2 (A), R3.2
unnamed: D28.2 (A), R4.2
unnamed: D29.2 (A), R5.2
unnamed: D30.2 (A), R6.2
unnamed: D31.2 (A), R7.2
unnamed: D32.2 (A), R8.2
unnamed: D33.2 (A), R9.2
unnamed: R2.1, U1.15 (QA)
unnamed: R3.1, U1.1 (QB)
unnamed: R4.1, U1.2 (QC)
unnamed: R5.1, U1.3 (QD)
unnamed: R6.1, U1.4 (QE)
unnamed: R7.1, U1.5 (QF)
unnamed: R8.1, U1.6 (QG)
unnamed: R9.1, U1.7 (QH)
unnamed: R10.2, R12.1, X1.1 (EN)
unnamed: R11.2, X1.3 (OUT)
PMOD_3V3: J3.11, J3.12, J5.11, J5.12, J7.11, J7.12, J8.11, J8.12, R1.2, TP4.1
ROT1A: J1.5, SW1.A
ROT1B: J1.7, SW1.B
ROT2A: J1.9, SW6.A
ROT2B: J1.11, SW6.B
ROT3A: J1.6, SW15.A
ROT3B: J1.8, SW15.B
ROT4A: J1.10, SW20.A
ROT4B: J1.12, SW20.B
ROT5A: J1.14, SW25.A
ROT5B: J1.16, SW25.B
ROW_0: J1.40, SW1.S1, SW2.1, SW3.1, SW4.1, SW5.1
ROW_1: J1.38, SW6.S1, SW7.1, SW8.1, SW9.1, SW10.1
ROW_2: J1.36, SW11.1, SW12.1, SW13.1, SW14.1, SW15.S1
ROW_3: J1.34, SW16.1, SW17.1, SW18.1, SW19.1, SW20.S1
ROW_4: J1.32, SW21.1, SW22.1, SW23.1, SW24.1, SW25.S1
TCK: J4.3, J6.3
TDI: J4.5, J6.5
TDO: J4.4, J6.4
TMS: J4.6, J6.6
adc0: RV1.2, U2.31 (GPIO26_ADC0)
adc1: RV2.2, U2.32 (GPIO27_ADC1)
adc2: RV3.2, U2.34 (GPIO28_ADC2)
fpga_ram_data_in: J11.1, U2.25 (GPIO19)
fpga_ram_data_out: J12.1, U2.21 (GPIO16)
fpga_ram_sck: J10.1, U2.24 (GPIO18)
fpga_rst: J9.1, U2.29 (GPIO22)
pico_fpga_0: U2.27 (GPIO21)
pico_fpga_1: U2.26 (GPIO20)
pico_fpga_2: U2.14 (GPIO10)
spi1_CSn: J13.2 (DAT3/CD), U2.17 (GPIO13)
spi1_rx: J13.7 (DAT0), R14.2, U2.16 (GPIO12)
spi1_sck: J13.5 (CLK), U2.19 (GPIO14)
spi1_tx: J13.3 (CMD), U2.20 (GPIO15)
uart1_rx: U2.12 (GPIO9)
uart1_tx: U2.11 (GPIO8)
usb_5v: J1.1, J2.1, TP1.1

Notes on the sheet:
cs0 mosi sck
need to change pins to reflext actual header pinout not the wacky PMOD one
need to hook up power!!!
TRACES NEED TO BE MATCHED FOR THIS PMOD
Attaches to carier board
which pins need pullups/downs
dac: mclk lr_clk sclk sdin
cs1 mosi sck
adc: mclk lr_clk sck sdout
d_c res vbatc vdcc
roterys buttons hfmi out lcd interface midi in audio in leds
CLK PIN
LEDS
osc
USED
pmod is 2 row connector with specific numbering
Accessible JTAG

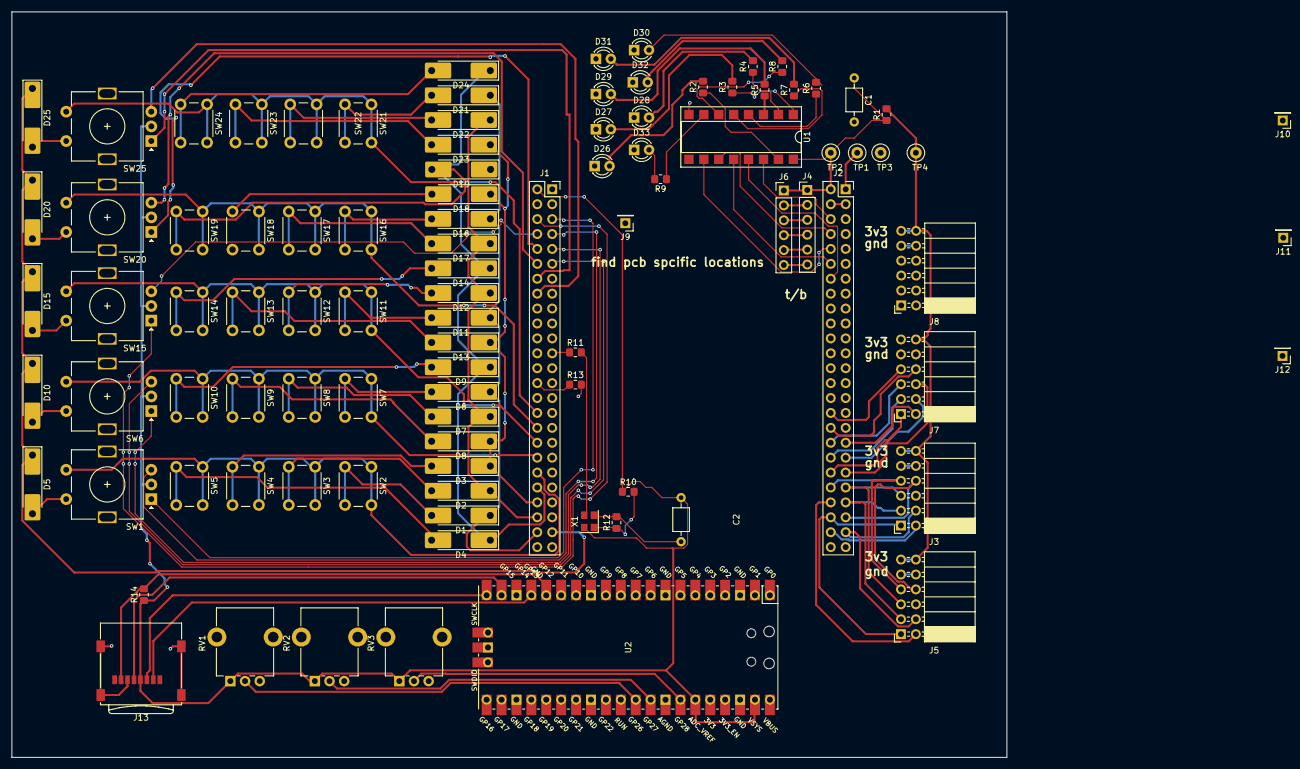
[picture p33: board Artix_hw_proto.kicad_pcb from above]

Board: 2 copper layers, 169.5 x 127.0 mm, 97 parts (0 on the bottom side), 109 nets.

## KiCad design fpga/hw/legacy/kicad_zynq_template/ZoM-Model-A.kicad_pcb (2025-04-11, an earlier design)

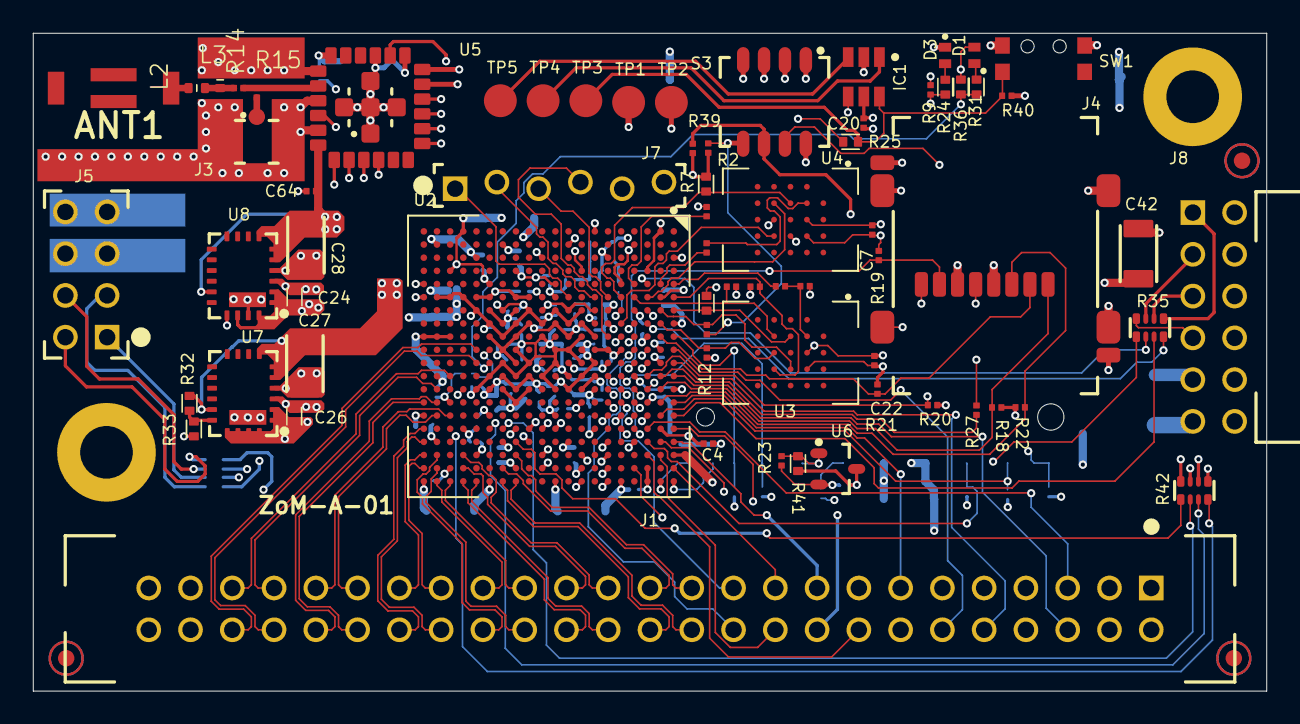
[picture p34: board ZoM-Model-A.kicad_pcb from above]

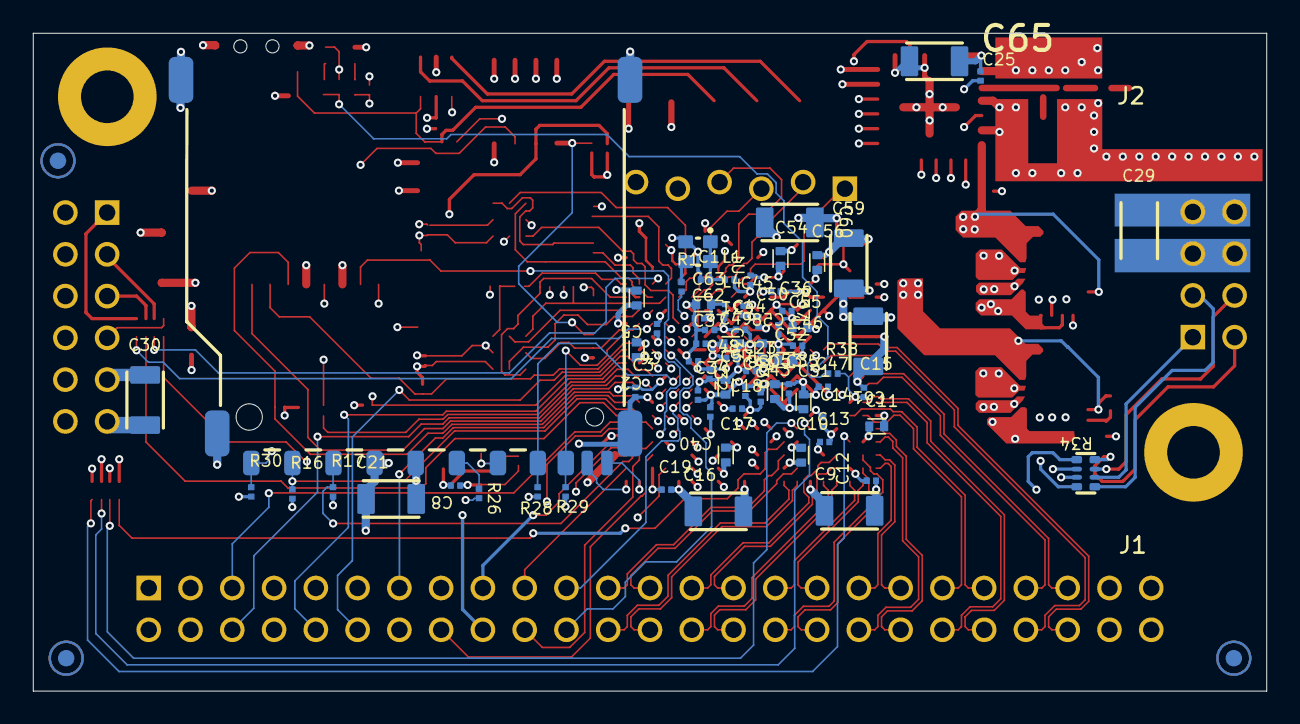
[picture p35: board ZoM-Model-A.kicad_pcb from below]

Board: 6 copper layers, 75.0 x 40.0 mm, 145 parts (72 on the bottom side), 140 nets.

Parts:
ANT1: Antena 2450AT43B100
C1, C8, C23, C34, C35, C36, C37, C41, C43, C44, C45, C46, C47, C48, C50, C64, C65: 470nF; CAPC0603X33N
C2, C5, C10, C11, C17, C24, C26, C63: 4.7µF; _AD_adlib_lib_pcb_TE-IPC7351_CAPC1005X60N.PcbLib_CAPC1005X6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
C3, C4, C6, C7, C12, C13, C14, C15, C18, C19, C20, C22, C31, C32, C33, C38, C39, C40, C62: 470nF; _AD_adlib_lib_pcb_TE-IPC7351_CAPC0603X33N.PcbLib_CAPC0603X3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
C9, C16, C21, C25, C27, C28, C29, C30, C42: 47µF; _AD_adlib_lib_pcb_TE-IPC7351_CAPC3216X180N.PcbLib_CAPC3216X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
C49, C51, C52, C53, C54, C55, C56: 4.7µF; _svn_cad_altium_pcb_contract_tt_tt-svn_ADLIB_dbww_.._lib_pc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
C57, C58: 4.7µF; CAPC1005X60N
C59, C60, C61: 100µF; CAPC3216X180N
D1: LED Red SML-P11UTT86; _AD_adlib_lib_pcb_TE-IPC7351_LEDC1006X25N_RED.PcbLib_LEDC10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
D3: LED Green SML-P11MTT86; _AD_adlib_lib_pcb_TE-IPC7351_LEDC1006X25N_GREEN.PcbLib_LEDC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
H1, H4: Mount.Hole 3.2mm; MHole3_2mm
IC1: Atmel AVR ATtiny10; _tfx_altium_lib_common_pcb_IC_IPC_SOT23-6.PcbLib_SOT23-6
J1: WANNE2,54-50 GERADE; _AD_adlib_lib_pcb_TE_WANNE2,54-50 GERADE.PcbLib_WANNE2,54-5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
J2: MMC SD Socket; _AD_adlib_lib_pcb_TE_104C-TAA0-R.PcbLib_104C-TAA0-R
J3: U.FL-R-SMT-1; _AD_adlib_lib_pcb_TE_U.FL-R-SMT-1.PcbLib_U.FL-R-SMT-1
J4: SCHD3A0100; _AD_adlib_lib_pcb_TE_SCHD3A0100.PcbLib_SCHD3A0100
J5: STIFTLEISTE2.54 OG 2R-8; STIFTLEISTE2_54 OG 2R-8
J7: Stiftleiste versetzt 1-reihig, 6pol.; _AD_adlib_lib_pcb_TE_STIFTLEISTE2_54 OG 1R-6V.PcbLib_STIFTL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
J8: PMod 2x6 Socket 90°; _AD_adlib_lib_pcb_TE_PMod2x6.PcbLib_PMod2x6
L1: BKP0603HS121-T; INDC0603X33N
L2, L3: IND-Ferrite; RESC1005X40R
L4: BKP0603HS121-T; _AD_adlib_lib_pcb_TE-IPC7351_INDC0603X33N.PcbLib_INDC0603X3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
PM1, PM2, PM3, PM4, PM5, PM6: FIDU-DOT - small
R1, R4, R8: 33R; RESC0603X26N
R2, R9, R10: 10K; RESC0603X26N
R3, R7, R24, R31: 470R; RESC1005X40N
R5, R6, R11, R12, R13, R16, R17, R18, R19, R20, R21, R22, R28, R29, R30, R39, R40: 10K; _AD_adlib_lib_pcb_TE-IPC7351_RESC0603X26N.PcbLib_RESC0603X2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
R14, R15: 0; RESC0603X26N
R23, R37: 4K7; _AD_adlib_lib_pcb_TE-IPC7351_RESC0603X26N.PcbLib_RESC0603X2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
R25: 470R; _AD_adlib_lib_pcb_TE-IPC7351_RESC1005X40N.PcbLib_RESC1005X4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
R26, R27: 33R; _AD_adlib_lib_pcb_TE-IPC7351_RESC0603X26N.PcbLib_RESC0603X2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
R32: 200K; _AD_adlib_lib_pcb_TE-IPC7351_RESC1005X40N.PcbLib_RESC1005X4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
R33: 301K; _AD_adlib_lib_pcb_TE-IPC7351_RESC1005X40N.PcbLib_RESC1005X4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
R34, R35, R42: 33R; _AD_adlib_lib_pcb_TE-IPC7351_RESCAX50P100X200X55-8N.PcbLib_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
R36: 680R; RESC1005X40N
R38: 4K7; RESC0603X26N
R41: 0R; _AD_adlib_lib_pcb_TE-IPC7351_RESC1005X40N.PcbLib_RESC1005X4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
S3: CHS-04TA; _AD_adlib_lib_pcb_TE-IPC7351_CHS-04TA.PcbLib_CHS-04TA
SW1: 4pin button; _tfx_altium_lib_common_pcb_BUT-SW_KMS221G_LFS.PcbLib_KMS221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
TP1, TP2, TP3, TP4, TP5: TP; _tfx_altium_lib_common_PCB_TP_TP-SMD-2mm.PcbLib_TP-SMD-2mm
U1: SiT8008AI-73-XXS-33.333333E; 2016
U2: XA7Z020-1CLG400I; _AD_adlib_lib_pcb_TE-IPC7351_BGA400C80P20X20_1700X1700X160N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
U3, U4: W25Q256FVBIG; _AD_adlib_lib_pcb_TE-IPC7351_BGA24C100P5X5_800X600X120N.Pcb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
U5: TiWi-uB2
U6: ATSHA204A-STUCZ-T; _AD_adlib_lib_pcb_TE-IPC7351_SOT95P237X112-3N.PcbLib_SOT95P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
U7, U8: EN5311QI; _AD_adlib_lib_pcb_TE_EN5311QI.PcbLib_EN5311QI

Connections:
1.8V: C16.1, C17.1, C18.1, C19.1, C23.1, C28.1, C32.2, C33.2, C44.1, C46.1, C48.1, C50.1, C52.1, C54.1, C56.1, C58.1, C60.2, C64.1, L4.2, U2.A3, U2.C19, U2.C20, U2.D2, U2.E5, U2.F8, U2.F11, U2.F18, U2.G1, U2.G9, U2.H4, U2.H8, U2.H14, U2.J9, U2.J11, U2.J17, U2.K8, U2.K20, U2.L3, U2.L11, U2.M8, U2.M16, U2.N9, U2.N11, U2.P2, U2.P10, U2.R5, U2.R9, U2.U1, U2.V4, U5.18, U8.5, U8.6, U8.7, U8.15
1V: C27.1, C34.1, C35.1, C36.1, C37.1, C38.1, C39.1, C40.1, C41.1, C43.1, C45.1, C47.1, C49.1, C51.1, C53.1, C55.1, C57.1, C59.1, C61.1, R32.1, U2.G7, U2.G11, U2.G13, U2.H10, U2.H12, U2.J7, U2.J13, U2.K12, U2.L7, U2.L13, U2.M12, U2.N7, U2.N13, U2.P8, U2.P12, U2.R7, U2.R13, U7.5, U7.6, U7.7, U7.15
3.3V: C2.1, C3.1, C4.1, C5.1, C6.1, C7.1, C8.1, C9.1, C10.1, C11.1, C12.1, C13.1, C14.1, C15.1, C20.1, C21.1, C22.2, C24.1, C25.1, C26.1, C29.1, C30.1, C31.2, C42.1, C65.1, D1.A, IC1.5, J1.1, J1.2, J1.49, J1.50, J2.4, J4.4, J5.7, J5.8, J7.6, J8.6, J8.12, L1.1, R2.2, R3.1, R5.2, R7.2, R16.1, R17.1, R18.1, R19.1, R20.1, R21.1, R22.1, R23.2, R28.1, R29.1, R30.1, R36.1, R37.2, R38.2, R39.1, R40.2, TP1.1, U2.A13, U2.B6, U2.B10, U2.B16, U2.D7, U2.D12, U2.E15, U2.K6, U2.M6, U2.N6, U2.N19, U2.R6, U2.R15, U2.T6, U2.T18, U2.U13, U2.V14, U2.W17, U2.Y20, U3.B4, U4.B4, U5.12, U6.2, U7.1, U7.2, U7.17, U7.18, U7.19, U7.20, U8.1, U8.2, U8.18, U8.20
B34_L1_N: J1.46, U2.T10
B34_L1_P: J1.44, U2.T11
B34_L4_N: J1.43, U2.W13
B34_L4_P: J1.45, U2.V12
B34_L7_N: J1.36, U2.Y17
B34_L7_P: J1.38, U2.Y16
B34_L8_N: J1.40, U2.Y14
B34_L8_P: J1.42, U2.W14
B34_L10_N: J1.39, U2.W15
B34_L10_P: J1.41, U2.V15
B34_L12_N: J1.29, U2.U19
B34_L12_P: J1.27, U2.U18
B34_L13_N: J1.25, U2.P19
B34_L13_P: J1.23, U2.N18
B34_L14_N: J1.26, U2.P20
B34_L14_P: J1.24, U2.N20
B34_L15_N: J1.30, U2.U20
B34_L15_P: J1.28, U2.T20
B34_L16_N: J1.33, U2.W20
B34_L16_P: J1.31, U2.V20
B34_L17_N: J1.35, U2.Y19
B34_L17_P: J1.37, U2.Y18
B34_L19_P: R42.3, U2.R16
B34_L21_P: R42.4, U2.V17
B34_L22_N: J1.32, U2.W19
B34_L22_P: J1.34, U2.W18
B34_L23_P: R42.1, U2.N17
B34_L24_N: R42.2, U2.P16
B35_L1_N: J2.11, U2.B20
B35_L2_N: J2.10, U2.A20
B35_L4_P: S3.7, U2.D19
B35_L6_N: U2.F17, U5.22
B35_L8_P: U2.M17, U5.2
B35_L9_P: U2.L19, U5.8
B35_L11_P: U2.L16, U5.3
B35_L14_N: U2.H18, U5.21
B35_L15_N: U2.F20, U5.19
B35_L15_P: U2.F19, U5.20
B35_L17_N: U2.H20, U5.16
B35_L21_N: U2.N16, U5.1
B35_L24_P: U2.K16, U5.4
BOOT_R: R2.1, R6.2, S3.5
BTN: IC1.6, R25.1, R40.1, SW1.2, TP3.1
DONE: R31.2, R36.2, U2.R11
GND: C1.2, C2.2, C3.2, C4.2, C5.2, C6.2, C7.2, C8.2, C9.2, C10.2, C11.2, C12.2, C13.2, C14.2, C15.2, C16.2, C17.2, C18.2, C19.2, C20.2, C21.2, C22.1, C23.2, C24.2, C25.2, C26.2, C27.2, C28.2, C29.2, C30.2, C31.1, C32.1, C33.1, C34.2, C35.2, C36.2, C37.2, C38.2, C39.2, C40.2, C41.2, C42.2, C43.2, C44.2, C45.2, C46.2, C47.2, C48.2, C49.2, C50.2, C51.2, C52.2, C53.2, C54.2, C55.2, C56.2, C57.2, C58.2, C59.2, C60.1, C61.2, C62.2, C63.2, C64.2, C65.2, D3.K, H1.1, H4.1, IC1.2, J1.3, J1.4, J1.47, J1.48, J2.3, J2.12, J3.2, J3.3, J4.6, J4.9, J4.10, J4.F1, J4.F2, J4.F3, J4.F4, J5.5, J5.6, J7.5, J8.5, J8.11, L3.2, R9.1, R10.1, R11.1, R13.1, R33.2, R41.2, S3.1, S3.2, S3.3, S3.4, SW1.3, SW1.4, TP2.1, U1.2, U2.A8, U2.A18, U2.B1, U2.B11, U2.C4, U2.C9, U2.C14, U2.D17, U2.E10, U2.E20, U2.F3, U2.F7, U2.F10, U2.G10, U2.G12, U2.G16, U2.H7, U2.H9, U2.H11, U2.H13, U2.H19, U2.J2, U2.J8, U2.J10, U2.J12, U2.K5, U2.K7, U2.K9, U2.K10, U2.K11, U2.K13, U2.K15, U2.L8, U2.L9, U2.L10, U2.L12, U2.L18, U2.M1, U2.M7, U2.M11, U2.M13, U2.N4, U2.N8, U2.N10, U2.N12, U2.N14, U2.P7, U2.P9, U2.P11, U2.P13, U2.P17, U2.R8, U2.R12, U2.R20, U2.T3, U2.T7, U2.T13, U2.U6, U2.U16, U2.V6, U2.V9, U2.V19, U2.W2, U2.W6, U2.W9, U2.W12, U2.Y5, U2.Y6, U2.Y9, U2.Y15, U3.B3, U4.B3, U5.5, U5.6, U5.7, U5.9, U5.13, U5.15, U5.17, U5.25, U5.26, U5.27, U5.28, U5.29, U6.3, U7.3, U7.4, U7.21, U8.3, U8.4, U8.17, U8.19, U8.21
INIT: R38.1, U2.R10
JTAG_R: R12.1, R39.2, S3.6
MEM_PROTECT: J2.6, R23.1, R41.1, U6.1
MIO7: R9.2, R24.2, U2.D8
MIO14: R35.6, U2.C5
MIO15: R35.8, U2.C8
MIO16: J1.19, U2.A19
MIO17: J1.21, U2.E14
MIO18: J1.20, U2.B18
MIO19: J1.22, U2.D10
MIO20: J1.17, U2.A17
MIO21: J1.18, U2.F14
MIO22: R34.7, U2.B17
MIO23: R34.8, U2.D11
MIO24: R34.5, U2.A16
MIO25: R34.6, U2.F15
MIO26: R35.7, U2.A15
MIO27: R35.5, U2.D13
MIO28: J1.5, U2.C16
MIO29: J1.7, U2.C13
MIO30: J1.9, U2.C15
MIO31: J1.11, U2.E16
MIO32: J1.13, U2.A14
MIO33: J1.15, U2.D15
MIO34: J1.6, U2.A12
MIO35: J1.8, U2.F12
MIO36: J1.10, U2.A11
MIO37: J1.12, U2.A10
MIO38: J1.14, U2.E13
MIO39: J1.16, U2.C18
MIO40: R26.1, U2.D14
MIO41: J2.2, R17.2, U2.C17
MIO42: J2.7, R28.2, U2.E12
MIO43: J2.8, R29.2, U2.A9
MIO44: J2.9, R30.2, U2.F13
MIO45: J2.1, R16.2, U2.B15
MIO46: J4.7, R19.2, U2.D16
MIO47: J4.3, R22.2, U2.B14
MIO48: R27.1, U2.B12
MIO49: J4.8, R20.2, U2.C12
MIO50: J4.1, R18.2, U2.B13
MIO51: J4.2, R21.2, U2.B9
MIO52: S3.8, U2.C10
MIO53: R25.2, U2.C11
NetANT1_1: ANT1.1, L2.2
NetC1_1: C1.1, L1.2, U1.1, U1.4
NetC62_1: C62.1, C63.1, L4.1, U2.G8
NetD1_K: D1.K, R31.1
NetD3_A: D3.A, R24.1
NetIC1_1: IC1.1, TP4.1
NetIC1_3: IC1.3, TP5.1
NetJ2_5: J2.5, R26.2
NetJ3_1: J3.1, R15.1
NetJ4_5: J4.5, R27.2
NetJ5_1: J5.1, R34.2
NetJ5_2: J5.2, R34.4
NetJ5_3: J5.3, R34.1
NetJ5_4: J5.4, R34.3
NetJ8_1: J8.1, R35.1
NetJ8_2: J8.2, R35.3
NetJ8_3: J8.3, R35.2
NetJ8_4: J8.4, R35.4
NetJ8_7: J8.7, R42.8
NetJ8_8: J8.8, R42.7
NetJ8_9: J8.9, R42.6
NetJ8_10: J8.10, R42.5
NetL2_1: L2.1, L3.1, R14.2
NetR1_1: R1.1, U1.3
NetR14_1: R14.1, R15.2, U5.14
NetR32_2: R32.2, R33.1, U7.16
PROG_B: R37.1, U2.L6
PS_CLK: R1.2, U2.E7
PS_POR_B: IC1.4, U2.C7
SPI0_CS: R3.2, U2.A7, U3.C2
SPI0_DQ1/M1: R13.2, U2.D6, U3.D2
SPI0_DQ2/M2: R6.1, U2.B7, U3.C4
SPI0_DQ3/M3: R5.1, U2.A6, U3.D4
SPI0_DQO/M0: R12.2, U2.B8, U3.D3
SPI0_SCK: R4.1, U2.A5
SPI0_SCK/M4: R4.2, R11.2, U3.B2
SPI1_CS: R7.1, U2.E6, U4.C2
SPI1_DQ0: U2.E9, U4.D3
SPI1_DQ1: U2.C6, U4.D2
SPI1_DQ2: U2.D9, U4.C4
SPI1_DQ3: U2.E8, U4.D4
SPI1_SCK: R8.1, U2.B5
SPI1_SCKR: R8.2, U4.B2
SPI_SCK_FB/VCFG1: R10.2, U2.D5
TCK: J7.4, U2.F9
TDI: J7.2, U2.G6
TDO: J7.3, U2.F6
TMS: J7.1, U2.J6

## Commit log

2025-04-11 added python tools for visualising video output frames and some scripts for debugging and genrating .coe files
2025-04-11 added targeted test builds for the digilent z720 and the QMtech artix. used for testing
    [or_based_matrix_dump.txt]
2025-04-11 added old legacy prototype pcbs, these are mostly not working examples. or part of learning how to design an interface for an FPGA
    [.kicad_sch, Artix_hw_proto.kicad_pcb, Artix_hw_proto.kicad_sch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]
2025-04-11 adding back the analoge side
    [shapes ramp values.ods]
2025-05-22 slew wrapper test forwards and reverse input directions. there are discontinuitys when switching the slew you are using, this could be avoided by resetting the averager whenever the slew mux is chang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
2025-05-22 trying to get modulation to work as the way of distorting the sinwave, seems like a better method, not currently working tho
2025-05-27 analog side connections all fixed up, no more loose wires
2025-06-02 alpha blend needed to be havily pipelined to meet 200mhz clk rate. 100mhz was fine tho sin wave gen had the same problem 100mhz clk was fine but 200 exposed the huge carry chain from using 12bit valu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
    oscilator is almost meeting timing now just 2.5ish ns slack
2025-06-03 more flip flops to tighten up the timing on the analog side. looks like it can pass timing at 200mhz (just analog side in isolation)
2025-06-10 switched to unsigned for better synthisis optimisation, digital side now meets 200mhz clock timing
